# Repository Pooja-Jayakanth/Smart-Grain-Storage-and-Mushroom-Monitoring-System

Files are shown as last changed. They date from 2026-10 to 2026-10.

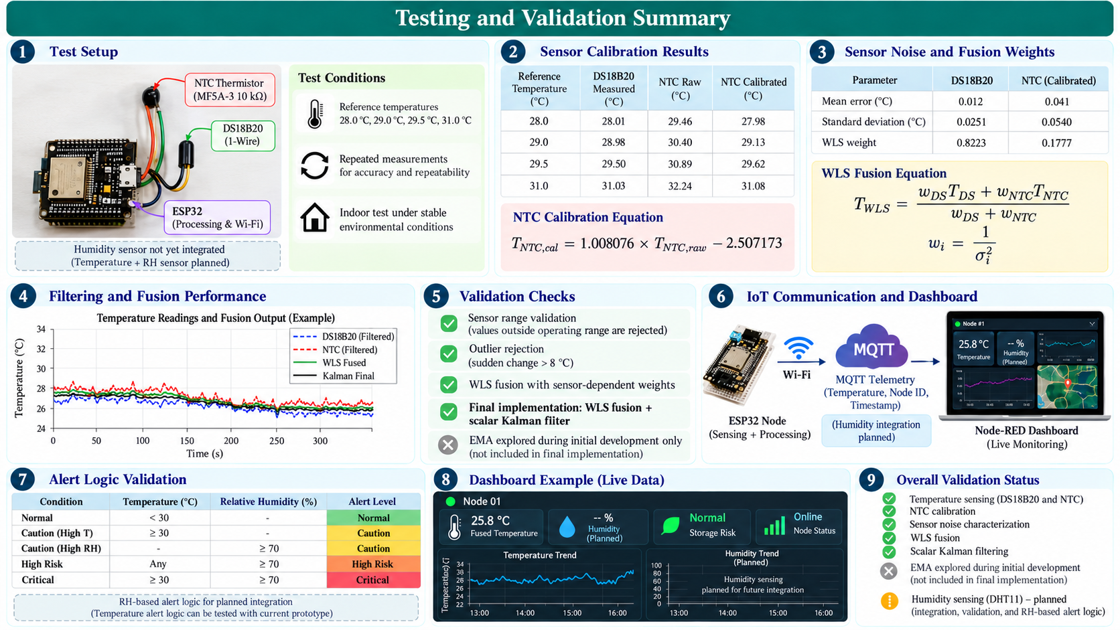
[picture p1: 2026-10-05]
docs/Testing and Validation Summary-Semifinal Prototype.png

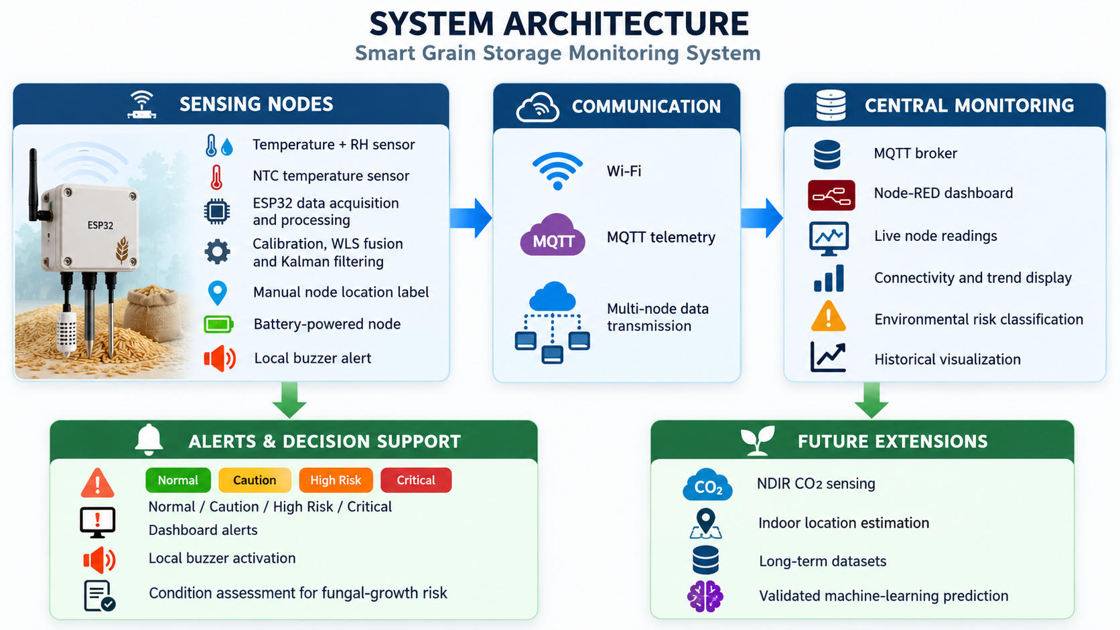
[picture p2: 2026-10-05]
docs/System Architecture.png

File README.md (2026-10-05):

# Smart Grain and Mushroom Monitoring System

## IoTrix 2.0 – Track C
### IoT Product & System Architecture

## Project Overview

The **Smart Grain and Mushroom Monitoring System** is a low-cost distributed IoT platform designed to monitor environmental conditions in **grain-storage facilities and mushroom-growing environments**.

Both applications are highly sensitive to environmental conditions. Temperature and relative humidity can significantly affect grain quality, fungal activity, mushroom growth conditions, and overall storage or cultivation performance.

The system uses multiple smart sensing nodes placed at selected locations within the monitored environment. Each node measures important environmental parameters, performs local processing, and transmits live telemetry to a centralized dashboard.

The project is being developed in three stages:

1. **Semi-final proof-of-concept prototype**
2. **Final competition product-level sensing node**
3. **Future data-driven, CO₂-monitoring, and machine-learning implementation**

---

# Problem Statement

Environmental conditions can vary significantly at different locations within a grain-storage warehouse or mushroom-growing facility.

For grain storage, unfavorable combinations of temperature and humidity can create conditions associated with spoilage, fungal activity, and deterioration.

For mushroom cultivation, temperature and relative humidity must remain within suitable ranges to maintain appropriate growing conditions.

Periodic manual measurements or a single sensing point may not provide sufficient information about spatial variations across the monitored environment.

A distributed monitoring system is therefore needed to:

- Continuously monitor environmental conditions at multiple locations
- Identify abnormal or unfavorable conditions early
- Provide centralized real-time visualization
- Generate local and remote alerts
- Store data for future analysis and predictive modelling

---

# Proposed Solution

The proposed system consists of multiple **ESP32-based smart environmental sensing nodes** deployed at selected locations.

Each node acquires environmental measurements, performs local processing, and transmits the processed data through **Wi-Fi using MQTT** to a centralized **Node-RED dashboard**.

The final system is designed to monitor:

- Temperature
- Relative humidity
- Node connectivity and operating status
- Overall environmental-condition level

The measured parameters will be combined using threshold-based decision logic derived from relevant research papers, technical sources, grain-storage guidance, and mushroom-growing requirements.

The dashboard will provide an interpreted condition such as:

- **NORMAL**
- **WARNING**
- **CRITICAL**

If unfavorable conditions are detected:

- A warning will be displayed on the dashboard
- A local buzzer at the relevant sensing node will be activated

This provides both **remote monitoring** and **local warning capability**.

---

# Target Applications

## Grain Storage Monitoring

The system can be deployed at multiple locations inside grain-storage facilities to monitor conditions associated with grain deterioration and fungal-growth risk.

The main parameters are:

- Fused temperature
- Relative humidity

The system is intended to indicate whether environmental conditions are becoming unfavorable rather than directly claiming the presence of fungal growth.

## Mushroom Environment Monitoring

The same distributed architecture can also be used in mushroom-growing environments.

The sensing nodes can continuously monitor:

- Temperature
- Relative humidity

The dashboard can indicate whether the environmental conditions remain within the selected operating ranges for the target mushroom-growing stage.

The threshold values for grain storage and mushroom monitoring will be application-specific and supported by relevant research and technical references.

---

# Development Stages

## 1. Semi-Final Prototype

The current prototype consists of **two operational wireless sensing nodes** connected to a centralized Node-RED monitoring dashboard.

### Components Used in the Semi-Final Prototype

Each prototype node currently contains:

- ESP32 microcontroller
- DS18B20 temperature sensor
- NTC thermistor
- NEO-6M GPS module
- OLED display
- Power-management circuitry
- Push button

For temperature measurement, a sensor-fusion architecture is implemented.

Temperature measurements from:

- DB18S20
- NTC thermistor

are processed using the:

- Calibration
- Sensor validation
- Outlier rejection
- Weighted Least Squares sensor fusion
- Kalman filtering

---

# Temperature Processing Architecture

```text
DB18S20 Temperature  NTC Temperature
        │               |
        │               |
        |               |
        │               │
        ▼               ▼
    Calibration     Calibration
        │               |
        │               |
        │               │
        └───────┬───────┘
                ▼
        Validity Checking
                ▼
         Outlier Rejection
                ▼
      Weighted Least Squares
          Sensor Fusion
                ▼
         Kalman Filtering
                ▼
       Final Temperature
```

Weighted Least Squares is used because the two temperature sensors have different measurement uncertainties.

Instead of assigning equal importance to both measurements, the fusion algorithm gives greater contribution to the more reliable sensor according to experimentally determined characteristics. Weights are given as inverse variances.

The fused output is then passed through a Kalman filter to reduce short-term fluctuations.

---

# Relative Humidity Measurement

The DHT11 also provides relative-humidity measurements.

Relative humidity is important in both target applications.

### For Grain Storage

Relative humidity contributes to the overall assessment of storage conditions associated with moisture-related deterioration and fungal-growth risk.

### For Mushroom Monitoring

Relative humidity is a key environmental parameter for maintaining suitable mushroom-growing conditions.

The measured RH value will therefore be evaluated together with the fused temperature in the final condition-assessment logic.

---

# Purpose of the GPS Module in the Prototype

The semi-final prototype includes a **NEO-6M GPS module** mainly for:

- Prototype development
- Location verification
- Node-position identification
- Testing
- Demonstration purposes

The GPS is not intended to operate continuously in the final product.

In many real deployments, sensing nodes will remain at known fixed positions. Keeping a GPS module active continuously would therefore add unnecessary hardware operation and power consumption.

---

# GPS Strategy in the Final Product

The custom PCB includes the required connections for temporarily connecting the GPS module.

During deployment, the GPS module can be connected when outdoor position acquisition is required.

The acquired location can then be saved by the system.

After the location has been stored, the GPS module can be removed.

```text
Installation
     ↓
Connect GPS Module
     ↓
Acquire Node Location
     ↓
Save Location Data
     ↓
Remove GPS Module
     ↓
Normal Monitoring Operation
```

This provides location capability when required without requiring a permanent GPS module in every deployed node.

---

# Purpose of the OLED in the Prototype

The OLED display is included in the semi-final prototype mainly for:

- Development
- Debugging
- Sensor verification
- Checking node status
- Demonstrating live operation

The OLED allows the development team to directly observe sensor readings and node status during testing.

---

# OLED Removal in the Final Product

The OLED is not required in the intended final monitoring node.

In practical deployment, the centralized dashboard will be the main user interface.

Removing the OLED from the final node helps to:

- Reduce unnecessary hardware
- Reduce power consumption
- Reduce product cost
- Simplify the sensing node
- Improve suitability for distributed deployment

---

# Final Competition Node Architecture

The final competition version of the sensing node is planned to include:

- ESP32 microcontroller
- DHT11 temperature and relative-humidity sensor
- NTC thermistor
- Buzzer
- Custom PCB
- Power-management circuitry
- Temporary GPS connection capability
- Local configuration / storage capability
- Custom mechanical enclosure

The GPS and OLED used in the development prototype will therefore not remain as continuously operating components in the final deployed node.

---

# Environmental Condition Assessment

The final system evaluates environmental conditions using:

- Fused temperature
- Relative humidity

The condition-assessment thresholds will be selected from relevant research papers and suitable technical sources.

Different threshold sets can be used depending on the selected application:

### Grain Storage Mode

The system will assess whether the environmental conditions are:

- Suitable
- Approaching an unfavorable range
- Associated with increased deterioration / fungal-growth risk

### Mushroom Monitoring Mode

The system will assess whether the environmental conditions are:

- Within the desired cultivation range
- Approaching an unsuitable range
- Outside the selected environmental limits

The system does not treat one sensor reading as direct proof of spoilage, contamination, fungal growth, or crop failure. Instead, it provides an **environmental-risk or suitability indication**.

---

# Condition Levels

```text
NORMAL
   │
   ├── Temperature and RH within selected operating limits
   │
WARNING
   │
   ├── One or more parameters approaching an unfavorable range
   │
CRITICAL
   │
   └── Temperature and/or RH outside selected acceptable limits
```

The exact limits will be documented together with the supporting research references.

---

# Live Telemetry

The system operates as a live IoT telemetry network.

Each sensing node continuously performs:

```text
Environmental Sensing
        ↓
Edge Processing
        ↓
Parameter Combination
        ↓
Condition Evaluation
        ↓
Wi-Fi
        ↓
MQTT
        ↓
Centralized Dashboard
```

Each node has a unique Node ID so that measurements from different locations can be identified independently.

---

# Communication Architecture

The sensing nodes communicate using:

- Wi-Fi
- MQTT
- Structured telemetry messages

```text
Sensing Node 01 ─┐
                 │
Sensing Node 02 ─┼── Wi-Fi
                 │
Sensing Node N ──┘
        ↓
   MQTT Broker
        ↓
     Node-RED
        ↓
Central Dashboard
```

MQTT provides a lightweight publish/subscribe communication method suitable for transmitting measurements from multiple IoT sensing nodes.

---

# Dashboard

The centralized monitoring dashboard is implemented using **Node-RED**.

The final dashboard is intended to display:

- Node ID
- Fused temperature
- Relative humidity
- Node connectivity
- Selected monitoring mode
- Environmental-condition classification
- Warning / critical status
- Historical trends
- Live telemetry
- Node location information
- Alarm indication

The dashboard therefore presents both the measured environmental parameters and the interpreted condition.

---

# Alert System

The final system contains both remote and local alert mechanisms.

## Dashboard Alert

When unfavorable environmental conditions are detected:

- The node status changes
- A warning or critical indication appears
- The affected sensing node is identified

## Local Buzzer Alert

A buzzer installed in the sensing node provides a local warning.

```text
Unfavorable Condition Detected
             ↓
      Decision Algorithm
          ┌──┴──┐
          ↓     ↓
     Dashboard  Buzzer
       Alert    Alert
```

This allows the system to provide an alert both remotely and directly at the monitored location.

---

# Prototype vs Final Product

| Feature | Semi-Final Prototype | Final Competition Model |
|---|---|---|
| ESP32 | ✅ | ✅ |
| DHT11 | ❌ | ✅ |
| DS18B20 | ✅ | ❌ Replaced by DHT11 |
| NTC Thermistor | ✅ | ✅ |
| Temperature Sensor Fusion | ✅ | ✅ |
| Relative Humidity | ✅ | ✅ |
| IRLZ44N | ✅ | ✅ |
| Wi-Fi | ✅ | ✅ |
| MQTT | ✅ | ✅ |
| Node-RED Dashboard | ✅ | ✅ |
| GPS | ✅ Development / verification | Temporary connection only |
| OLED | ✅ Development / verification | ❌ Removed |
| Push button | ✅ | ❌ Removed |
| Buzzer | Under development | ✅ |
| Custom PCB | Designed | ✅ |
| Custom Enclosure | Designed | ✅ |
| Live Telemetry | ✅ | ✅ |
| Grain Condition Assessment | Under development | ✅ |
| Mushroom Condition Assessment | Under development | ✅ |
| CO₂ Monitoring | ❌ | Future implementation |
| Machine Learning | ❌ | Future development |

---

# Current Proof of Concept

At the semi-final stage, the project has achieved:

- Two operational sensing nodes
- DB18S20 temperature measurement
- NTC temperature measurement
- Temperature sensor calibration
- WLS temperature sensor fusion
- Kalman filtering
- Sensor validity checking
- ESP32 edge processing
- Wi-Fi connectivity
- MQTT telemetry
- Node identification
- Centralized Node-RED dashboard
- GPS-based prototype location verification
- OLED-based local prototype visualization
- Custom PCB design
- Mechanical enclosure design

This demonstrates the complete core IoT chain:

```text
Physical Measurement
        ↓
Edge Processing
        ↓
Wireless Communication
        ↓
IoT Messaging
        ↓
Centralized Monitoring
```

---

# Technology Stack

## Hardware

- ESP32
- DHT11 temperature and relative-humidity sensor
- DS18B20 for prototype development
- NTC thermistor
- Buzzer
- NEO-6M GPS for development / temporary location initialization
- OLED for prototype development
- Pushbutton for prototype development
- Custom PCB
- Custom enclosure
- Power-management circuitry
- IRLZ44N MOSFET

## Embedded Processing

- Sensor acquisition
- Calibration
- Validity checking
- Outlier rejection
- Weighted Least Squares sensor fusion
- Kalman filtering
- Temperature and RH condition evaluation
- Alarm control

## Communication

- Wi-Fi
- MQTT
- Structured telemetry payloads

## Monitoring

- Node-RED
- Real-time dashboard
- Multi-node visualization
- Historical trends
- Alerts
- Telemetry logging

---

# Engineering Design Philosophy

## Low Cost

The sensing nodes use low-cost and widely available embedded components so that multiple nodes can be deployed practically.

## Distributed Monitoring

Multiple sensing nodes can be placed at different locations instead of relying on a single measurement point.

## Edge Processing

Important sensor processing is performed directly on the ESP32 before data transmission.

## Modular Architecture

The same node and communication architecture can support different environmental-monitoring applications.

## Reduced Final Hardware

Development-only components such as the OLED and continuously operating GPS are removed from the final product when no longer required.

## Dual-Parameter Monitoring

The current condition assessment uses temperature and relative humidity, which are directly relevant to the environmental suitability of grain storage and mushroom cultivation.

## Dual-Application Architecture

The same sensing platform can support:

- Grain-storage environmental monitoring
- Mushroom-growing environmental monitoring

The monitoring logic and threshold values can be configured according to the selected application.

---

# Current Limitations

The current system is still at the prototype and semi-final development stage.

Current limitations include:

- Buzzer integration is still being completed
- DHT11 calibration and integration is still being completed.
- Grain-condition assessment logic requires final validation
- Mushroom-condition assessment logic requires final validation
- Threshold values must be fully documented using relevant research sources
- The custom PCB requires physical fabrication and validation
- Long-duration testing in representative environments is still required
- Power consumption and battery life require further characterization
- Wi-Fi availability may affect live communication
- Larger-scale multi-node deployment requires further validation

---

# Planned Improvements Before the Final Competition

The following improvements are planned before the final competition:

1. Complete buzzer integration.
2. Finalize the combined temperature and RH assessment logic.
4. Define separate threshold sets for grain storage and mushroom monitoring.
5. Document threshold values using relevant research papers and technical sources.
6. Manufacture and test the custom PCB.
7. Integrate the PCB into the designed enclosure.
8. Remove the OLED from the final node.
9. Implement temporary GPS-based location initialization.
10. Improve the dashboard for multi-parameter monitoring.
11. Add application selection for grain-storage or mushroom-monitoring mode.
12. Implement dashboard and local buzzer alerts.
13. Perform longer-duration sensor and communication testing.
14. Test the system under representative grain-storage and mushroom-growing conditions.
15. Measure power consumption and estimate operating duration.
16. Improve Wi-Fi reconnection and network-loss handling.

---

# Future Implementation – CO₂ Level Monitoring

A future version of the system may include a **dedicated NDIR CO₂ sensor** to provide direct CO₂ concentration measurements in ppm.

CO₂ monitoring could add useful information for both applications.

## Grain Storage

Changes in CO₂ concentration can provide an additional indicator of biological respiration and changing storage conditions. In a future implementation, CO₂ measurements could be evaluated together with fused temperature, relative humidity, and historical trends to strengthen environmental-risk assessment.

## Mushroom Monitoring

CO₂ concentration is an important environmental parameter in mushroom-growing environments. A future node could therefore use direct NDIR CO₂ monitoring together with temperature and relative humidity to provide more complete cultivation-condition monitoring.

The future sensing concept would become:

```text
Temperature
    +
Relative Humidity
    +
NDIR CO₂ Measurement
    ↓
Improved Environmental
Condition Assessment
```

A dedicated NDIR sensor would be used rather than estimating CO₂ indirectly.

---

# Future Development – Data Logging and Machine Learning

The current system uses research-based thresholds and interpretable engineering decision logic.

As a future development, long-term environmental data collected from deployed sensing nodes will be stored and used to develop application-specific datasets.

The datasets may include:

- Temperature
- Relative humidity
- CO₂ concentration when future CO₂ sensing is implemented
- Time information
- Node / location information
- Selected application
- Environmental-condition classification
- Verified grain-quality observations where reliable labels are available
- Verified mushroom-growth or environmental observations where reliable labels are available

These datasets can later be used to investigate machine-learning methods for more advanced prediction.

## Future Grain Monitoring

A validated model could be investigated for earlier identification of environmental patterns associated with grain deterioration risk.

## Future Mushroom Monitoring

A separate validated model could be investigated for identifying environmental patterns associated with suitable or unsuitable mushroom-growing conditions.

The long-term development path is:

```text
Live IoT Monitoring
        ↓
Historical Data Collection
        ↓
Dataset Development
        ↓
CO₂ Monitoring Extension
        ↓
Data Analysis
        ↓
Machine-Learning Model Training
        ↓
Model Validation
        ↓
Deployment of Validated Model
        ↓
Improved Predictive Monitoring
```

Machine learning is considered a future enhancement rather than a requirement for the current proof of concept.

The current threshold-based system provides an interpretable engineering baseline before sufficient representative and correctly labelled field data are available for model training.

---

# Expected Final System Architecture

```text
       SMART GRAIN & MUSHROOM
          MONITORING SYSTEM

 ┌─────────────────────────────────────┐
 │               NODE 01               │
 │                                     │
 │ DHT11 → Temperature + RH            │
 │ NTC   → Temperature                 │
 │                                     │
 │                                     │
 │ ESP32                               │
 │ ├── Calibration                     │
 │ ├── Sensor Validation               │
 │ ├── Temperature Sensor Fusion       │
 │ ├── Kalman Filtering                │
 │ ├── Condition Assessment            │
 │ └── Alarm Logic                     │
 │                                     │
 │ Buzzer                              │
 └──────────────────┬──────────────────┘
                    │
                    │ Wi-Fi / MQTT
                    │
        ┌───────────┴───────────┐
        │                       │
      NODE 02                 NODE N
        │                       │
        └───────────┬───────────┘
                    ▼
               MQTT Broker
                    ▼
                 Node-RED
                    ▼
            CENTRAL DASHBOARD
                    │
       ┌────────────┼────────────┐
       ▼                         ▼
 Temperature                     RH
       │                         │
       └────────────┼────────────┘
                    ▼
       Application-Specific
        Condition Assessment
                    ▼
         NORMAL / WARNING /
              CRITICAL

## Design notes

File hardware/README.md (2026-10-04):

# Hardware

This folder contains the hardware design files for the Smart Grain Storage and Mushroom Monitoring System.

The current hardware development includes the sensing-node schematic, PCB design, bill of materials, and mechanical enclosure design.

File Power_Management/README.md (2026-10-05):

Power management calculations of the System

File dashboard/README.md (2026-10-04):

# Dashboard 

## Overview

This folder contains the dashboard implementation for the **Smart Grain Storage and Mushroom Monitoring System for Sri Lankan grain storage facilities**.

The dashboard receives environmental data from multiple ESP32-based wireless sensor nodes through **Wi-Fi and MQTT** and provides centralized real-time monitoring using **Node-RED**.

The main purpose of the dashboard is to help identify storage conditions that may increase the risk of fungal growth and grain deterioration by monitoring parameters such as:

- Temperature
- Relative humidity
- Temperature variation over time
- Battery status
- Wi-Fi signal strength
- Node connectivity
- Risk level
- Alarm condition

> The system does not directly identify or confirm the presence of fungi.  
> It identifies environmental conditions and trends that may indicate an increased risk of fungal growth and grain deterioration.

---

## System Architecture

```text
        SMART GRAIN STORAGE MONITORING SYSTEM

 ┌──────────────────────┐
 │     Sensor Node 01   │
 │ Temperature          │
 │ Humidity             │
 │ NTC Temperature      │
 │ Battery Monitoring   │
 └──────────┬───────────┘
            │
            │
 ┌──────────▼───────────┐
 │     Sensor Node 02   │
 │ Temperature          │
 │ Humidity             │
 │ NTC Temperature      │
 │ Battery Monitoring   │
 └──────────┬───────────┘
            │
            │
 ┌──────────▼───────────┐
 │     Sensor Node N    │
 └──────────┬───────────┘
            │
            │ Wi-Fi
            ▼
 ┌──────────────────────┐
 │ Wi-Fi Router / AP    │
 └──────────┬───────────┘
            │
            ▼
 ┌──────────────────────┐
 │     MQTT Broker      │
 └──────────┬───────────┘
            │
            ▼
 ┌──────────────────────┐
 │       Node-RED       │
 │      Dashboard       │
 └──────────┬───────────┘
            │
   ┌────────┼───────────────┐
   │        │               │
   ▼        ▼               ▼
Live Data  Trends        Alerts
   │
   ▼
Storage Zone Monitoring

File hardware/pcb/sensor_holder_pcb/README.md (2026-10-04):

# Sensor Holder PCB

This folder consists of all the files related to the sensor holder PCB.

This sensor holder PCB consists of our both sensors NTC Thermistor and DHT11 Temperature and relative humidity sensor.

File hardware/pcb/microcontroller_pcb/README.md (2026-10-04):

# Microcontroller PCB

This folder consists of all the files related to the Microcontroller section.

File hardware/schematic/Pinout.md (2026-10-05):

# Temperature Node – Pinout / Connection List

---

## 1. ESP-12F / ESP8266 Main Pinout
__________________________________________________________________________________________________________________________
| ESP-12F Pin | ESP-12F Signal | PCB Connection | Connected Component / Net | External / Manual Connection |
|---|---|---|---|---|
| 1 | RST | Reset circuit | R9.1, SW4.1/SW4.2, 10 kΩ pull-up | |
| 2 | ADC | External header | R2.1, **H2.5** | NTC 10 kohm |
| 3 | EN | Pull-up | R5.1, 10 kΩ pull-up network | |
| 4 | IO16 | Pull-up | R6.1, 10 kΩ pull-up | |
| 5 | IO14 | NC | Not connected in schematic | |
| 6 | IO12 | NC | Not connected in schematic | |
| 7 | IO13 | NC | Not connected in schematic | |
| 8 | VCC | 3.3 V rail | U7 VOUT, C2/C3, CN4.4, H2.2 | |
| 9 | CS0 | NC | Not connected in schematic | |
| 10 | MISO | NC | Not connected in schematic | |
| 11 | IO9 | Buzzer | U8.1 | |
| 12 | IO10 | NC | Not connected in schematic | |
| 13 | MOSI | NC | Not connected in schematic | |
| 14 | SCLK | MOSFET gate drive | R3.2 → R3 100 Ω → Q1 gate | |
| 15 | GND | Ground | GND / H2.1 / H2.4 / U5.2 / SW3.4 | |
| 16 | IO15 | Boot pull-down | R8.2, R8.1 → GND | |
| 17 | IO2 | Pull-up | R7.1, 10 kΩ pull-up | |
| 18 | IO0 | Programming / boot| R7.1, U5.1; jumper to GND through U5 | |
| 19 | IO4 | External header | **H2.3** | DS18B20 Temparature sensor |
| 20 | IO5 | Push button | SW3.1; SW3.4 → GND | |
| 21 | RXD | External header | **CN4.3** | Header for programming & GPS |
| 22 | TXD | External header | **CN4.2** | Header for programming & GPS |

---

## 2. External Connector CN4 – 4 Pin Header

**Part:** HC-EH2.54-4A-TW  
**PCB footprint:** 1×4, 2.5 mm pitch
______________________________________________________________________________
| CN4 Pin | PCB Net / Connection | Manual External Function |
|---|---|---|
| 1 | Q1 Drain / MOSFET switched output | GND of GPS (optional) |
| 2 | ESP-12F TXD (Pin 22) | Header for programming & GPS |
| 3 | ESP-12F RXD (Pin 21) | Header for programming & GPS |
| 4 | 3.3 V / ESP-12F VCC | VCC of GPS (optional) |

---

## 3. External Header H2 – 5 Pin Header

**Part:** 1×5, 2.54 mm pitch
_____________________________________________________________
| H2 Pin | PCB Connection | Manual External Function |
|---|---|---|
| 1 | GND | GND of DS18B20 |
| 2 | 3.3 V | VCC of DS18B20 |
| 3 | ESP-12F IO4 (Pin 19)  | Input pin for DS18B20 |
| 4 | GND | GND of NTC |
| 5 | ESP-12F ADC (Pin 2) | Input pin for NTC data |

---

## 4. Power Connector CN5 – 2 Pin

**Part:** JST-PH-2-SMT-RA
___________________________________
| CN5 Pin | PCB Connection |
|---|---|
| 1 | U7 VIN / input supply |
| 2 | GND |

### Power path

`CN5.1 → U7 VIN → AMS1117-3.3 → 3.3 V`

`CN5.2 → GND`

---

## 5. Programming Jumper U5

**Part:** 2-pin jumper
__________________________________________________________________________
| U5 Pin | Connection | Function |
|---|---|---|
| 1 | ESP-12F IO0 / Pin 18 | Short circuited while upload programme |
| 2 | GND | Short circuited while upload programme |

### Programming operation

For ESP8266 UART programming:

**U5 ON / shorted:** IO0 → GND

**U5 OFF / open:** IO0 pulled HIGH for normal boot

---

## 6. Push Button for getting GPS locatiion SW3
___________________________________________________
| SW3 Pin | Connection |
|---|---|
| 1 | ESP-12F IO5 / Pin 20 |
| 2 | Not explicitly connected in schematic |
| 3 | Not explicitly connected in schematic |
| 4 | GND |

---

## 7. Reset Button SW4
___________________________________________________
| SW4 Pin | Connection |
|---|---|
| 1 | ESP-12F RST / Pin 1 |
| 2 | ESP-12F RST / Pin 1 |
| 3 | GND |
| 4 | Not explicitly connected in schematic |

---

## 8. MOSFET Q1

**Part:** IRLZ44PBF
_______________________________________________________________
| Q1 Pin | MOSFET Pin Name | PCB Connection |
|---|---|---|
| 1 | Gate (G) | R3.1 → R3 100 Ω → ESP-12F Pin 14 |
| 2 | Drain (D) | CN4.1 |
| 3 | Source (S) | GND through R4/R8 ground network |

---

## 9. Buzzer U8

**Part:** HX-2212
_________________________________
| U8 Pin | Connection |
|---|---|
| 1 | ESP-12F IO9 / Pin 11 |
| 2 | GND |

---

## 10. Voltage Regulator U7

**Part:** AMS1117-3.3
__________________________________
| U7 Pin | Function | Connection |
|---|---|---|
| 1 | GND | GND |
| 2 | VOUT | 3.3 V rail |
| 3 | VIN | CN5.1 |
| 4 | VOUT | 3.3 V rail |

---

## 11. Important Pull-Up / Pull-Down Resistors
______________________________________________________
| Resistor | Value | Connection |
|---|---|---|
| R2 | 10 kΩ | 3.3 V → ESP ADC |
| R3 | 100 Ω | ESP Pin 14 → MOSFET gate |
| R4 | 10 kΩ | MOSFET gate → GND |
| R5 | 10 kΩ | ESP EN pull-up |
| R6 | 10 kΩ | ESP IO16 pull-up |
| R7 | 10 kΩ | ESP IO2 / IO0 pull-up network |
| R8 | 10 kΩ | ESP IO15 pull-down |
| R9 | 10 kΩ | ESP RST pull-up |

---

## 12. Capacitors
______________________________________________
| Capacitor | Value | Connection |
|---|---|---|
| C1 | 10 µF | Input supply filtering |
| C2 | 10 µF | 3.3 V output filtering |
| C3 | 100 nF| 3.3 V decoupling |

---

# 14. ESP8266 GPIO Usage Summary
___________________________________________________________
| GPIO | ESP-12F Pin | Current Use |
|---|---|---|
| GPIO0 | 18 | Programming / boot jumper |
| GPIO1 / TXD | 22 | UART TX → CN4.2 |
| GPIO2 | 17 | Pull-up / boot |
| GPIO3 / RXD | 21 | UART RX ← CN4.3 |
| GPIO4 | 19 | H2.3 external |
| GPIO5 | 20 | SW3 button |
| GPIO6 | 9 | Flash interface / CS0 |
| GPIO7 | 13 | Flash interface / MOSI |
| GPIO8 | 12 | Flash interface / IO10 |
| GPIO9 | 11 | Buzzer |
| GPIO10 | 12 | Flash interface / IO10 |
| GPIO12 | 6 | NC |
| GPIO13 | 7 | NC |
| GPIO14 | 5 | NC |
| GPIO15 | 16 | Boot pull-down |
| GPIO16 | 4 | Pull-up |
| ADC0 | 2 | H2.5 external ADC |
| RST | 1 | Reset switch |
| EN | 3 | 10 kΩ pull-up |
| VCC | 8 | 3.3 V |
| GND | 15 | Ground |

---

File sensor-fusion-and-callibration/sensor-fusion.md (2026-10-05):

# Sensor Fusion Pipeline — Semi-Finals Prototype

## 1. Sensor-Fusion Objective

The purpose of the sensor-fusion subsystem is to obtain a temperature estimate that is more reliable than depending on only one sensor.

The two temperature sensors use different measurement principles:

- **DS18B20** — digital temperature sensor using the 1-Wire interface.
- **NTC thermistor** — analog resistive temperature sensor read using the ESP32 ADC through a voltage-divider circuit.

Because the two sensors have different levels of noise, calibration error, and measurement uncertainty, they are **not treated as equally reliable**.

The processing method was developed in stages.

### Initial Development

```text
Raw Sensor Measurement
        ↓
EMA Filtering
        ↓
Filtered Sensor Measurement
```

### Final Implemented Processing

```text
Sensor Acquisition
        ↓
Calibration
        ↓
Range Validation
        ↓
Outlier Rejection
        ↓
Sensor Validity Check
        ↓
Weighted Least Squares (WLS) Fusion
        ↓
Fused Temperature + Fused Variance
        ↓
Scalar Kalman Filter
        ↓
Final Temperature Estimate
```

---

## 2. Sensors Used

### 2.1 DS18B20

The DS18B20 provides a direct digital temperature value to the ESP32.

**Main features**

- Digital temperature measurement
- 1-Wire communication
- Does not require the ESP32 ADC
- Lower measured noise than the NTC sensor
- Provides one independent temperature measurement for fusion
- Uses a **4.7 kΩ pull-up resistor** on the data line

The DS18B20 path is:

```text
DS18B20
   ↓
Digital Temperature Reading
   ↓
Calibration
   ↓
Validation
   ↓
Outlier Rejection
   ↓
WLS Fusion
```

### 2.2 MF5A-3 10 kΩ NTC Thermistor

The MF5A-3 is the analog temperature sensor used in the prototype.

The thermistor is connected as a voltage divider:

```text
3.3 V
  │
10 kΩ Fixed Resistor
  │
  ├── ESP32 ADC
  │
10 kΩ NTC
  │
 GND
```

Parameters used:

| Parameter | Value |
|---|---:|
| Nominal resistance, R₀ | 10 kΩ |
| Reference temperature, T₀ | 298.15 K |
| Beta constant, B | 3950 K |
| ESP32 ADC resolution | 12 bit |
| Maximum ADC count | 4095 |

The NTC path is:

```text
NTC Voltage Divider
        ↓
ADC Sampling
        ↓
20-Sample Averaging
        ↓
Resistance Calculation
        ↓
Beta Equation
        ↓
Raw NTC Temperature
        ↓
Linear Calibration
        ↓
Validation
        ↓
Outlier Rejection
        ↓
WLS Fusion
```

---

## 3. NTC ADC Averaging

The NTC ADC reading is averaged over **20 samples** before converting it to resistance.

The 20 ADC samples are:

```math
ADC_1,\ ADC_2,\ ADC_3,\ldots,\ ADC_{20}
```

The average ADC value is:

```math
ADC_{\mathrm{avg}}
=
\frac{1}{20}\sum_{i=1}^{20} ADC_i
```

This averaged value is used in the resistance calculation.

---

## 4. NTC Resistance Calculation

The NTC resistance is calculated from the voltage-divider output as:

```math
R_{\mathrm{NTC}}
=
R_{\mathrm{fixed}}
\frac{ADC_{\mathrm{avg}}}
{ADC_{\max}-ADC_{\mathrm{avg}}}
```

where:

```math
R_{\mathrm{fixed}} = 10{,}000\ \Omega
```
```math
ADC_{\max}=4095
```

for the 12-bit ESP32 ADC.

---

## 5. NTC Resistance-to-Temperature Conversion

The measured NTC resistance is converted to temperature using the Beta equation:

```math
\frac{1}{T_K}
=
\frac{1}{T_0}
+
\frac{1}{B}
\ln\left(
\frac{R_{\mathrm{NTC}}}{R_0}
\right)
```

where:

```math
T_0 = 298.15\ \mathrm{K}
```
```math
R_0 = 10{,}000\ \Omega
```
```math
B = 3950\ \mathrm{K}
```

The raw NTC temperature in degrees Celsius is:

```math
T_{\mathrm{NTC,raw}}
=
T_K - 273.15
```

---

## 6. Sensor Calibration

Both temperature sensors were experimentally compared against a reference thermometer at:

- 28.0 °C
- 29.0 °C
- 29.5 °C
- 31.0 °C

The calibration stage was used to distinguish **systematic measurement error** from **random measurement variation**.

### 6.1 DS18B20 Calibration

The DS18B20 did not show a consistent fixed positive or negative bias across the tested temperatures.

Therefore, no additional linear correction was applied.

```math
T_{\mathrm{DS,cal}}
=
T_{\mathrm{DS,raw}}
```

The calibration coefficients are therefore:

```math
A_{\mathrm{DS}}=1
```
```math
B_{\mathrm{DS}}=0
```

### 6.2 NTC Calibration

The NTC showed a systematic positive offset and therefore required linear calibration.

The general calibration equation is:

```math
T_{\mathrm{cal}}
=
A\,T_{\mathrm{raw}} + B_c
```

The experimentally obtained coefficients for the NTC are:

```math
A_{\mathrm{NTC}}=1.008076
```
```math
B_{\mathrm{NTC}}=-2.507173
```

Therefore:

```math
T_{\mathrm{NTC,cal}}
=
1.008076\,T_{\mathrm{NTC,raw}}
-
2.507173
```

This calibrated NTC temperature is used for fusion.

---

## 7. Initial EMA Filtering Stage

During the initial development stage, an **Exponential Moving Average (EMA)** filter was tested to reduce short-term fluctuations in the individual sensor measurements.

The EMA equation is:

```math
T_{\mathrm{EMA},k}
=
\alpha T_k+(1-\alpha)T_{\mathrm{EMA},k-1}
```

where:

- **T(k)** = current sensor measurement
- **T_EMA(k−1)** = previous filtered value
- **T_EMA(k)** = new filtered value
- **α** = smoothing coefficient

The value used during testing was:

```math
\alpha = 0.20
```

Therefore:

```math
T_{\mathrm{EMA},k}
=
0.20T_k
+
0.80T_{\mathrm{EMA},k-1}
```

The initial development flow was:

```text
DS18B20 Raw
    ↓
EMA
    ↓
Filtered DS18B20

NTC Raw
    ↓
EMA
    ↓
Filtered NTC
```

EMA was useful because it:

- required very little memory,
- required low computation,
- reduced sample-to-sample fluctuations,
- and was simple to implement on the ESP32.

However, EMA only performs **temporal smoothing**. It does not determine how much each sensor should be trusted relative to the other.

For that reason, EMA was not used as the final fusion method.

---

## 8. Measurement Validation

Before sensor fusion, each calibrated temperature is checked for validity.

The prototype applies two main checks.

### 8.1 Range Validation

The selected valid operating range is:

```math
-20^\circ\mathrm{C}
<
T
<
100^\circ\mathrm{C}
```

Measurements at or outside the limits are rejected.

### 8.2 Sudden-Change Rejection

A new measurement is rejected if the change from the previous accepted measurement is greater than:

```math
8^\circ\mathrm{C}
```

That is:

```math
\left|T_k-T_{k-1}\right|
>
8^\circ\mathrm{C}
```

is treated as an invalid sudden change.

This check helps reject:

- disconnected-sensor readings,
- transient ADC disturbances,
- conversion errors,
- unrealistic spikes.

---

## 9. Sensor Noise Characterization

The measured standard deviations from the 100-sample characterization test were:

```math
\sigma_{\mathrm{DS}}
=
0.0251^\circ\mathrm{C}
```
```math
\sigma_{\mathrm{NTC}}
=
0.0540^\circ\mathrm{C}
```

The DS18B20 therefore showed lower random variation than the NTC.

These measured values are used directly in the WLS fusion algorithm.

---

## 10. Weighted Least Squares Sensor Fusion

The final fusion method is **inverse-variance Weighted Least Squares (WLS)**.

The main idea is:

> A sensor with lower experimentally measured variance is given a larger weight.

The variance of each sensor is:

```math
\sigma_{\mathrm{DS}}^2
=
(0.0251)^2
=
0.000630
```

```math
\sigma_{\mathrm{NTC}}^2
=
(0.0540)^2
=
0.002916
```

### 10.1 Information Values

For each sensor, the information value is the inverse of its variance:

```math
I_{\mathrm{DS}}
=
\frac{1}{\sigma_{\mathrm{DS}}^2}
```

```math
I_{\mathrm{NTC}}
=
\frac{1}{\sigma_{\mathrm{NTC}}^2}
```

A lower sensor variance therefore produces a larger information value.

### 10.2 WLS Weights

The information values are normalized to obtain the sensor weights:

```math
w_{\mathrm{DS}}
=
\frac{I_{\mathrm{DS}}}
{I_{\mathrm{DS}}+I_{\mathrm{NTC}}}
```

```math
w_{\mathrm{NTC}}
=
\frac{I_{\mathrm{NTC}}}
{I_{\mathrm{DS}}+I_{\mathrm{NTC}}}
```

The experimentally derived weights are approximately:

```math
w_{\mathrm{DS}}\approx0.822
```
```math
w_{\mathrm{NTC}}\approx0.178
```

and:

```math
w_{\mathrm{DS}}+w_{\mathrm{NTC}}=1
```

This means that the DS18B20 contributes more strongly because it showed lower measured noise.

### 10.3 Fused Temperature

The WLS fused temperature is:

```math
T_{\mathrm{WLS}}
=
w_{\mathrm{DS}}T_{\mathrm{DS}}
+
w_{\mathrm{NTC}}T_{\mathrm{NTC}}
```

Using the experimentally obtained weights:

```math
T_{\mathrm{WLS}}
=
0.822\,T_{\mathrm{DS}}
+
0.178\,T_{\mathrm{NTC}}
```

Therefore:

- DS18B20 contribution ≈ 82.2%
- NTC contribution ≈ 17.8%

The NTC is still retained as an independent second temperature measurement, providing redundancy.

---

## 11. Fused Measurement Variance

WLS also produces an uncertainty value for the fused measurement.

The fused variance is:

```math
R_{\mathrm{WLS}}
=
\frac{1}
{
\frac{1}{\sigma_{\mathrm{DS}}^2}
+
\frac{1}{\sigma_{\mathrm{NTC}}^2}
}
```

This value represents the uncertainty of the WLS fused temperature.

The WLS stage therefore produces two important outputs:

- `T_WLS` — fused temperature
- `R_WLS` — fused measurement variance

The fused variance is passed directly to the Kalman filter as the measurement-noise term.

---

## 12. Fault-Tolerant Fusion

The fusion stage checks the validity of both temperature sensors.

### Both Sensors Valid

Normal WLS fusion is used:

```math
T_{\mathrm{WLS}}
=
0.822\,T_{\mathrm{DS}}
+
0.178\,T_{\mathrm{NTC}}
```

### Only DS18B20 Valid

- **w_DS = 1**
- **w_NTC = 0**

Therefore:

```math
T_{\mathrm{WLS}}=T_{\mathrm{DS}}
```

### Only NTC Valid

- **w_DS = 0**
- **w_NTC = 1**

Therefore:

```math
T_{\mathrm{WLS}}=T_{\mathrm{NTC}}
```

### Both Sensors Invalid

The fusion result is declared invalid.

```text
DS18B20 Invalid
       +
NTC Invalid
       ↓
Fusion Invalid
       ↓
No false temperature output
```

This allows the system to continue operating when only one temperature sensor fails.

---

## 13. Kalman Filtering After WLS

WLS combines the two simultaneous temperature measurements at a single sampling instant.

The Kalman filter then uses the sequence of WLS results over time.

```text
WLS
 ↓
Combines the two sensors at one sampling instant

Kalman Filter
 ↓
Tracks and smooths the fused temperature over time
```

The Kalman filter provides temporal smoothing while considering the uncertainty generated by the WLS stage.

---

## 14. Kalman Filter State

The state being estimated is the true temperature:

```math
x_k=T_k
```

---

## 15. Prediction Step

The predicted temperature is assumed to remain close to the previous estimate:

```math
\hat{x}_{k|k-1}
=
\hat{x}_{k-1|k-1}
```

The predicted covariance is:

```math
P_k^{-}
=
P_{k-1}+Q
```

---

## 16. Process Noise

The process-noise standard deviation used in the prototype is:

```math
\sigma_Q=0.10
```

Therefore:

```math
Q=(0.10)^2=0.01
```

This term represents expected real temperature variation between consecutive samples.

---

## 17. Measurement Noise

The measurement-noise term used by the Kalman filter is obtained directly from WLS:

```math
R_k=R_{\mathrm{WLS}}
```

This directly connects the WLS stage to the Kalman filter.

---

## 18. Kalman Gain

The Kalman gain is calculated as:

```math
K_k
=
\frac{P_k^{-}}
{P_k^{-}+R_k}
```

Interpretation:

- Smaller **R(k)** → greater confidence in the new WLS measurement
- Larger **R(k)** → greater reliance on the predicted temperature

---

## 19. Kalman Measurement Update

The WLS fused temperature becomes the Kalman measurement input:

```math
z_k=T_{\mathrm{WLS}}
```

The updated temperature estimate is:

```math
\hat{x}_k
=
\hat{x}_{k|k-1}
+
K_k\left(
z_k-\hat{x}_{k|k-1}
\right)
```

The covariance is then updated as:

```math
P_k
=
(1-K_k)P_k^{-}
```

The resulting value **x̂(k)** is the final temperature estimate.

---

## 20. Complete Sensor-Fusion Flow

```text
                         DS18B20
                            │
                            ▼
                 Digital Temperature
                            │
                            ▼
                       Calibration
                  T_DS,cal = T_DS,raw
                            │
                            ▼
                    Range Validation
                            │
                            ▼
                    Outlier Rejection
                            │
                            ▼
                     Validity Check
                            │
                            │
                            ├───────────────┐
                            │               │
                            │               ▼
                            │          WLS SENSOR
                            │            FUSION
                            │               ▲
                            │               │
                            │               │
                         NTC Thermistor     │
                            │               │
                            ▼               │
                    ESP32 ADC Sampling      │
                            │               │
                            ▼               │
                    20-Sample Average       │
                            │               │
                            ▼               │
                  Resistance Calculation    │
                            │               │
                            ▼               │
                      Beta Equation         │
                            │               │
                            ▼               │
                     T_NTC,raw              │
                            │               │
                            ▼               │
                    Linear Calibration      │
                            │               │
                            ▼               │
                     T_NTC,cal              │
                            │               │
                            ▼               │
                    Range Validation        │
                            │               │
                            ▼               │
                    Outlier Rejection       │
                            │               │
                            ▼               │
                     Validity Check         │
                            │               │
                            └───────────────┘
                                    │
                                    ▼
                     Weighted Least Squares
                                    │
                         ┌──────────┴──────────┐
                         │                     │
                         ▼                     ▼
                    T_WLS                 R_WLS
                         │                     │
                         └──────────┬──────────┘
                                    ▼
                         Scalar Kalman Filter
                                    │
                                    ▼
                       Final Temperature Estimate
```

---

## 21. Development Flow from EMA to Final Fusion

```text
INITIAL DEVELOPMENT
───────────────────

Raw DS18B20 ──→ EMA ──→ Filtered DS18B20

Raw NTC ──────→ EMA ──→ Filtered NTC

Purpose:
Evaluate basic short-term noise reduction.

        ↓

SENSOR CHARACTERIZATION
───────────────────────

Reference Temperature Testing
        ↓
Calibration
        ↓
Noise Measurement
        ↓
Standard Deviation
        ↓
Sensor Variance

        ↓

FINAL IMPLEMENTATION
────────────────────

DS18B20 + NTC
        ↓
Sensor Acquisition
        ↓
NTC 20-Sample ADC Averaging
        ↓
NTC Temperature Conversion
        ↓
Calibration of Both Sensors
        ↓
Range Validation
        ↓
Sudden-Change / Outlier Rejection
        ↓
Sensor Validity Decision
        ↓
Inverse-Variance WLS Fusion
        ↓
T_WLS + R_WLS
        ↓
Scalar Kalman Filter
        ↓
Final Temperature Estimate
```

---

## 22. Why the Final Method Was Selected

The final architecture is:

```text
Calibration
    ↓
Validity Checking
    ↓
WLS Sensor Fusion
    ↓
Kalman Filtering
```

This approach was selected because:

- the two sensors have different measured uncertainties,
- WLS uses measured sensor variance rather than arbitrary weighting,
- the more reliable sensor automatically receives a larger weight,
- the second sensor still provides redundancy,
- one sensor can temporarily replace the other during a fault,
- WLS produces a fused measurement variance,
- the fused variance can be passed directly to the Kalman filter,
- the Kalman filter smooths the fused temperature over time,
- the complete method is computationally suitable for the ESP32,
- and the method is transparent and easy to justify experimentally.

---

## 23. Why EMA Was Replaced

EMA was useful for initial filtering.

Its equation is:

```math
T_{\mathrm{EMA},k}
=
\alpha T_k+(1-\alpha)T_{\mathrm{EMA},k-1}
```

However, EMA uses a fixed coefficient **α**.

It does not use the experimentally measured variance of each sensor.

WLS instead uses:

```math
w_i\propto\frac{1}{\sigma_i^2}
```

so the sensor weights come directly from measured sensor performance.

Therefore:

```text
EMA
 ↓
Initial temporal smoothing investigation

WLS
 ↓
Final multi-sensor fusion

Kalman Filter
 ↓
Final temporal estimation and smoothing
```

---

## 24. Why Simple Averaging Was Not Used

A simple average would be:

```math
T_{\mathrm{avg}}
=
\frac{T_{\mathrm{DS}}+T_{\mathrm{NTC}}}{2}
```

which assumes:

```math
w_{\mathrm{DS}}=0.5
```
```math
w_{\mathrm{NTC}}=0.5
```

This would incorrectly treat both sensors as equally reliable.

The measured standard deviations show that the sensors are not equally reliable.

Therefore, inverse-variance WLS was selected instead.

---

## 25. Why Median Fusion Was Not Used

Median fusion is useful when at least three redundant measurements are available.

This prototype uses only two independent temperature sensors.

Therefore, median-based voting cannot provide meaningful majority-based fault rejection.

---

## 26. Why Complementary Filtering Was Not Used

Complementary filtering is typically useful when two sensors provide complementary information over different frequency ranges.

In this system:

- DS18B20 measures temperature.
- NTC thermistor measures temperature.

Both sensors measure the same physical quantity over the same timescale.

Therefore, a complementary filter does not provide a clear advantage.

---

## 27. Why an Extended Kalman Filter Was Not Required

The NTC measurement starts with a nonlinear resistance-to-temperature relationship.

However, that nonlinearity is handled before sensor fusion:

```text
NTC Resistance
      ↓
Beta Equation
      ↓
Temperature
      ↓
Linear Calibration
```

By the time fusion begins:

```text
DS18B20 → Temperature in °C
NTC     → Temperature in °C
```

Both inputs are already temperature values in the same domain.

Therefore, a nonlinear estimator such as an Extended Kalman Filter is not required.

---

## 28. Key Prototype Parameters

| Parameter | Value |
|---|---:|
| DS18B20 sensor | Digital temperature sensor |
| NTC sensor | MF5A-3 10 kΩ |
| NTC fixed resistor | 10 kΩ |
| NTC Beta constant | 3950 K |
| ESP32 ADC resolution | 12 bit |
| ADC maximum | 4095 |
| NTC ADC averaging | 20 samples |
| Calibration points | 28.0, 29.0, 29.5, 31.0 °C |
| DS18B20 calibration | `T_cal = T_raw` |
| NTC calibration slope | 1.008076 |
| NTC calibration offset | −2.507173 |
| DS18B20 standard deviation | 0.0251 °C |
| NTC standard deviation | 0.0540 °C |
| DS18B20 WLS weight | ≈ 0.822 |
| NTC WLS weight | ≈ 0.178 |
| EMA test coefficient | 0.20 |
| Sudden-change rejection | > 8 °C |
| Validation range | −20 °C < T < 100 °C |
| Kalman process-noise standard deviation | 0.10 |
| Kalman process noise, Q | 0.01 |
| Kalman measurement noise | `R(k) = R_WLS` |

---

## 29. Final Sensor-Fusion Summary

For the **semi-finals prototype**, the complete temperature-estimation path is:

```text
DS18B20 + MF5A-3 NTC
        ↓
Sensor Acquisition
        ↓
NTC 20-Sample ADC Averaging
        ↓
Temperature Conversion
        ↓
Sensor Calibration
        ↓
Range Validation
        ↓
Outlier Rejection
        ↓
Sensor Validity / Fault Handling
        ↓
Inverse-Variance WLS Sensor Fusion
        ↓
Fused Temperature T_WLS
+
Fused Variance R_WLS
        ↓
Scalar Kalman Filter
        ↓
Final Temperature Estimate
```

The **EMA filter is retained as part of the development history**, while the **final implemented sensor-fusion architecture is WLS followed by scalar Kalman filtering**.

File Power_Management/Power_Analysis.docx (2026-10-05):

POWER ANALYSIS AND BATTERY SELECTION

ESP-12F Temperature / Humidity Monitoring Node with 5-Minute MQTT Transmission

Engineering project article — design calculation, battery sizing and low-power operating strategy

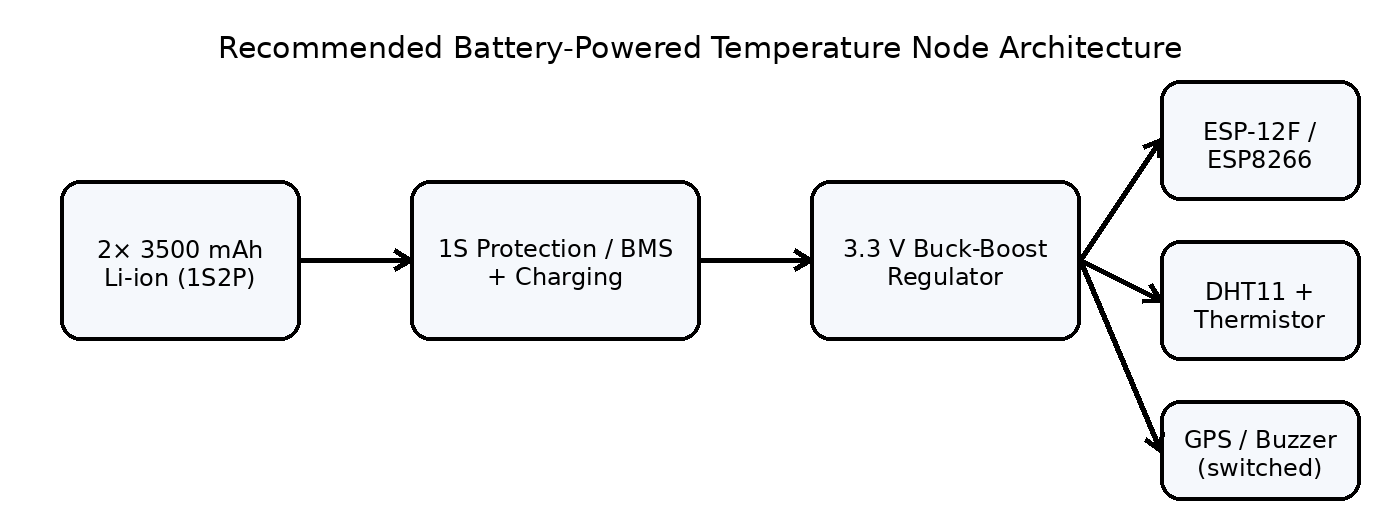
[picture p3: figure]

Figure 1. Recommended power architecture for the battery-powered temperature node.

# 1. System Definition

The proposed node uses an ESP-12F/ESP8266 as the wireless controller. A DHT11 measures ambient temperature and relative humidity, while an external thermistor provides an additional temperature measurement through an analogue divider. The GPS receiver is not a continuous sensing load: it is used only during initialization to obtain the node location, after which the location can be stored and the GPS powered off. The measured data are transmitted to the MQTT server once every 5 minutes.

For a long-life battery design, the ESP8266 should not remain connected to Wi-Fi continuously. The recommended operating sequence is: wake from deep sleep, read the sensors, connect to Wi-Fi, publish one MQTT message, disconnect, and return to deep sleep for approximately 300 s.

Parameter | Design value
MQTT transmission interval | 5 min (300 s)
MQTT messages per hour | 12
MQTT messages per day | 288
Battery arrangement | 1S2P — two 3500 mAh cells in parallel
Nominal battery voltage | 3.6–3.7 V
Nominal battery capacity | 7000 mAh
Nominal stored energy | 25.90 Wh
Regulated electronics rail | 3.3 V
GPS operation | Initialization only; OFF during normal monitoring

# 2. Component Power Data and Design Assumptions

The calculation uses manufacturer/datasheet values where available. Because the exact Wi-Fi association time, RF transmit duty cycle, thermistor resistance, and GPS model were not specified, a conservative engineering case is also included. The conservative case should be used for battery sizing.

Load | Value used | Basis
ESP8266 active/Wi-Fi interval | 100 mA for 5 s per cycle | Conservative design assumption; actual RF current varies
ESP8266 deep sleep | 20 µA | Espressif datasheet value
DHT11 measurement | 0.3 mA | DHT11 specification
DHT11 standby | 60 µA | DHT11 specification
Thermistor divider | 0.165 mA | 10 kΩ + 10 kΩ assumed at 3.3 V
3.3 V converter efficiency | 90% | Conservative engineering assumption
Converter quiescent current | 25 µA | Representative TPS63031 typical value

Espressif specifies an average operating current of about 80 mA for the ESP8266EX and reports 20 µA in deep sleep. Its RF section can draw substantially higher instantaneous current during transmission; the datasheet gives typical TX values of 120–170 mA depending on 802.11 mode. Espressif also gives a directly relevant example in which a temperature sensor sleeps for 300 s and then wakes to connect to the access point, with an overall average ESP8266 current below 1 mA.

# 3. Battery Configuration

Two 3500 mAh single-cell Li-ion batteries are selected in parallel, not in series. This produces a 1S2P pack: the voltage remains approximately 3.6–3.7 V nominal while the capacity becomes approximately 7000 mAh.

C_pack = 3500 mAh + 3500 mAh = 7000 mAh

E_pack ≈ 7.0 Ah × 3.7 V = 25.9 Wh

A protected 3500 mAh 18650 is a suitable cell class for this design. If unprotected Samsung INR18650-35E cells are used instead, a dedicated 1S protection/BMS circuit is mandatory. Cells connected in parallel should be matched, at similar state of charge, and from the same cell type/batch where practical. The protection and charging circuit must be designed for a 1S Li-ion pack with a 4.2 V charge limit.

# 4. Five-Minute MQTT Power Calculation

## 4.1 ESP8266 average current

Assume the ESP8266 is active for 5 s during each 300 s cycle at 100 mA. For the remaining 295 s it is in deep sleep at 20 µA = 0.020 mA.

I_ESP,avg = [(100 mA × 5 s) + (0.020 mA × 295 s)] / 300 s = 1.686 mA

## 4.2 DHT11 average current

The DHT11 is assumed to spend 1 s in its measurement state during each 5-minute cycle and to remain in its specified standby state for the rest of the interval.

I_DHT,avg = [(0.3 mA × 1 s) + (0.060 mA × 299 s)] / 300 s = 0.061 mA

## 4.3 Thermistor divider current

A 10 kΩ thermistor with a 10 kΩ fixed resistor is assumed for the analogue divider. At 3.3 V, the divider current is approximately:

I_divider = 3.3 V / (10 kΩ + 10 kΩ) = 0.165 mA

## 4.4 Total 3.3 V load

I_3V3,avg = 1.686 + 0.061 + 0.165 = 1.912 mA

The buzzer is assumed to be OFF during normal operation. The GPS is also excluded from the continuous load because it is powered only during location initialization.

## 4.5 Battery-side current through a buck-boost converter

A single-cell Li-ion battery cannot be regulated to 3.3 V over its complete discharge range by a simple AMS1117 LDO without losing usable battery capacity. A buck-boost converter is therefore recommended. For the calculation, 90% conversion efficiency is used.

I_bat,avg = (3.3 V × 1.912 mA) / (3.7 V × 0.90) + 0.025 mA = 1.920 mA

# 5. Battery Runtime

A practical design should not assume that every last milliamp-hour of the nominal battery capacity is usable. An 80% usable-capacity factor is applied to account for converter cutoff, cell voltage limits, temperature, ageing, and capacity tolerance.

C_usable = 7000 mAh × 0.80 = 5600 mAh

Runtime = 5600 mAh / 1.920 mA = 2917 h ≈ 121.5 days

Operating assumption | Average battery current | Estimated runtime
Conservative design case: 5 s active / 295 s deep sleep | 1.920 mA | 121.5 days
Espressif-style <1 mA ESP average + sensor loads | 1.240 mA | 188.2 days
No deep sleep; Wi-Fi maintained, ~15 mA modem-sleep baseline | 15.11 mA | 15.4 days

The large difference between the first and third cases is the key design result. Reducing the MQTT interval alone is not sufficient if the ESP8266 remains awake. The major battery-life improvement comes from putting the ESP8266 into deep sleep between measurements.

# 6. Daily Energy and Data Transmission

Quantity | Result
Messages per day | 288
Conservative average battery current | 1.920 mA
Approx. battery charge consumed per day | 46.1 mAh/day
Approx. nominal battery energy | 25.90 Wh
Approx. daily battery energy consumption | 0.170 Wh/day

At one MQTT message every 5 minutes, the node generates 12 messages per hour and 288 messages per day. This is generally adequate for environmental monitoring and reduces wireless activity by a factor of 300 compared with a one-message-per-second schedule.

# 7. GPS Initialization Energy

The GPS receiver is not part of the continuous power budget because it is used only to initialize the node location. As an engineering example, if a GPS receiver draws 50 mA for 60 s during initial acquisition, the one-time consumption is:

E_GPS,initial ≈ 50 mA × 1 h/60 = 0.83 mAh

This is negligible compared with a 7000 mAh battery. The exact GPS energy should nevertheless be recalculated using the selected receiver's datasheet and actual time-to-first-fix.

# 8. Regulator and Power-Path Recommendation

The existing AMS1117-3.3 arrangement should not be the preferred final power stage for a single-cell Li-ion battery. An LDO wastes the voltage difference as heat and, more importantly, cannot maintain 3.3 V once the cell voltage falls below the regulator's required headroom.

A buck-boost converter such as the TI TPS63031 is a suitable design reference because it accepts 1.8–5.5 V input, provides a fixed 3.3 V option, supports up to 500 mA in boost operation at 3.3 V, and has a typical quiescent current of 25 µA. The exact regulator should be selected after checking component availability, PCB layout requirements, and the ESP-12F's peak-current demand.

Power-stage item | Recommended implementation
Battery | 2 × 3500 mAh Li-ion, 1S2P, 3.6–3.7 V nominal
Protection | 1S Li-ion protection/BMS with overcharge, over-discharge and over-current protection
Regulator | 3.3 V buck-boost, ≥500 mA output capability preferred
ESP supply | 3.3 V regulated rail with local bulk + ceramic decoupling
DHT11 | 3.3 V supply; power-gate if further optimization is required
Thermistor | 10 kΩ divider; preferably switch divider power during deep sleep
GPS | Load-switched; ON only during initialization
Buzzer | Normally OFF
MQTT interval | 300 s
ESP sleep mode | Deep sleep between transmissions

# 9. Peak Current and Hardware Margin

Battery capacity determines runtime, but it does not guarantee reliable operation. The ESP8266 can draw much higher instantaneous current during Wi-Fi transmission than its long-term average. The power rail must therefore be designed for the peak load, not only the calculated average.

The ESP8266EX datasheet lists typical Wi-Fi TX currents of 120 mA for 802.11n, 140 mA for 802.11g, and 170 mA for 802.11b under specified test conditions. The regulator and PCB decoupling network should therefore provide adequate transient response. A practical design target is a regulated 3.3 V rail capable of at least 500 mA, with the exact margin verified experimentally.

# 10. Practical Battery-Life Optimization

• Use deep sleep rather than keeping the Wi-Fi association alive between MQTT transmissions.

• Power the GPS only during the initialization procedure and store the acquired location in non-volatile memory.

• Switch off the thermistor divider during deep sleep if the firmware/hardware permits it; this removes the continuous 0.165 mA divider current.

• Use a buck-boost regulator instead of AMS1117-3.3 for the final single-cell design.

• Avoid indicator LEDs that remain continuously powered; their current can become significant relative to the deep-sleep load.

• Place low-ESR bulk capacitance and ceramic decoupling close to the ESP-12F power pins to handle Wi-Fi current transients.

• Use matched cells in the 1S2P battery pack and provide proper 1S protection and charging.

• Validate the theoretical runtime using an ammeter/data logger because Wi-Fi retry time and access-point signal strength can dominate the actual wake energy.

# 11. Engineering Conclusion

For the proposed temperature-monitoring node, changing the MQTT interval to 5 minutes and using two 3500 mAh cells in a 1S2P arrangement gives a 7 Ah, approximately 25.9 Wh nominal battery pack. With deep sleep between transmissions, the calculated conservative battery-side average current is approximately 1.92 mA, giving an estimated runtime of about 122 days after applying an 80% usable-capacity factor. The actual runtime can be higher or lower depending primarily on Wi-Fi connection time, RF retries, regulator efficiency, sensor powering strategy, and battery condition.

If the ESP8266 is kept awake instead of using deep sleep, the same battery is expected to last only on the order of 15 days under the simplified 15 mA modem-sleep baseline. Therefore, deep sleep is the principal design requirement for achieving a genuinely long-lasting 5-minute MQTT node.

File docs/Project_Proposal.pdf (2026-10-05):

# IoTRiX 2.0

T R A C K C · P R O J E C T P R O P O S A L

# Smart Grain Storage and Mushroom Monitoring System

### A distributed, low-cost IoT platform for continuous temperature and relative humidity

monitoring in Sri Lankan grain storage houses and mushroom cultivation rooms.

T E A M N A M E : S I S Y P H U S

T E A M M E M B E R S :

### J.J.K. Pooja S. Juththis S. Kishown S. Aksaraan

Smart Grain Storage and Mushroom Monitoring System | Team Sisyphus | IoTRiX 2.0
Project Proposal · Track C | Page ii

# Table of Contents

Executive Summary | 1
1 Introduction and Background | 1
2 Problem Statement | 1
3 Aim and Objectives | 2
4 Scope of the Project | 2
5 Proposed Methodology | 3
6 Current Progress and Validation Plan | 6
7 Work Plan and Project Management | 7
8 Resources and Budget | 8
9 Risks and Mitigation | 10
10 Expected Outcomes and Significance | 10
11 Future Development | 10
12 Conclusion | 11
References | 11

## List of Figures and Tables

Figure 5.1: Proposed System Architecture and Development Boundaries | 3
Figure 5.2: Node-Level Processing and System Data Flow | 5
Table 5.1: Hardware Functions | 3
Table 6.1: Current Development Progress | 6
Table 6.2: Testing and Evaluation Plan | 6
Table 7.1: Implementation Milestones | 7
Table 8.1: Prototype Bill of Materials | 8
Table 8.2: Budget for One Final-Product Unit | 9
Table 9.1: Risks and Proposed Mitigation | 10

## Executive Summary

The Smart Grain Storage and Mushroom Monitoring System proposes an affordable, distributed Internet of Things (IoT) platform for monitoring temperature and relative humidity in Sri Lankan grain storage houses and mushroom cultivation rooms. Multiple sensing locations will provide operators with a clearer view of environmental variation and support timely action when conditions move outside application-specific limits.

Each wireless node uses an ESP32, a DHT11 temperature and relative humidity sensor, and an NTC thermistor. The temperature measurements are processed using Weighted Least Squares (WLS) fusion followed by Kalman filtering. Telemetry is transmitted over Wi-Fi using MQTT to a centralized Node-RED dashboard. The platform will support separate grain storage and mushroom monitoring configurations, with dashboard warnings and local buzzer alerts.

The current proof of concept comprises two operational nodes, each with two temperature sensors, and a working sensing-to-dashboard communication path. A custom PCB and enclosure have been designed; fabrication, full electrical validation, buzzer integration, and application-specific condition assessment remain to be completed. The proposal sets out the methodology, validation activities, implementation milestones, resource requirements, and risks involved in developing the prototype into a deployable system.

## 1 Introduction and Background

Grain storage and mushroom cultivation require environmental observations that reflect conditions across the monitored space. A reading taken at one location or during an occasional inspection may not represent changes elsewhere in a storage house or growing room. A distributed monitoring system can make these variations visible and provide a continuous record for operational decisions. In stored grain this matters because cereals conduct heat poorly, so local temperature changes and hot spots can remain confined to part of the store. Grain degradation depends mainly on temperature, moisture and oxygen, and the safe moisture level falls as temperature rises; storage fungi require a relative humidity of at least about 65% and grow at roughly 10–40 °C.

For Sri Lankan grain storage houses, the proposed approach uses accessible sensing locations across relevant storage zones. For mushroom cultivation, nodes can be placed in different growing areas or racks. The same hardware platform can serve both applications through different threshold configurations, reducing the need to develop two separate systems.

This proposal focuses on the end-to-end system architecture, sensing and processing method, custom hardware, dashboard, deployment process, and engineering validation relevant to an IoT product submission under Track C. Wireless nodes avoid cabling and give real-time access to readings, so abnormal conditions can be detected and acted on promptly; low-cost wireless sensors have been used in this way in other settings, such as preventive conservation in museums.

## 2 Problem Statement

Operators need a practical way to identify unsuitable temperature and relative humidity conditions across multiple locations. Periodic manual observations and isolated measurements offer limited visibility of how conditions vary with location and time. This can delay recognition of environmental conditions associated with grain deterioration or unsuitable mushroom cultivation conditions.

The engineering problem is therefore to develop an affordable multi-node platform that acquires dependable measurements, communicates them reliably, and presents application-specific warnings. The system must also distinguish sensor or communication faults from environmental warnings and remain accessible for installation and maintenance.

## 3 Aim and Objectives

### 3.1 Project aim

To develop and validate a modular IoT system for continuous, multi-point temperature and relative humidity monitoring in grain storage and mushroom cultivation environments.

### 3.2 Specific objectives

### 1. Develop ESP32 sensing nodes with DHT11 and NTC temperature measurements and DHT11

relative humidity acquisition.

2. Calibrate and evaluate the temperature sensors, implement WLS fusion and Kalman filtering, and compare the processed estimate with reference measurements.
3. Provide Wi-Fi and MQTT telemetry to a Node-RED dashboard with unique node identification and connectivity reporting.

### 4. Implement and validate separate application thresholds, NORMAL, WARNING, and CRITICAL

states, and local and dashboard alerts.

### 5. Fabricate and validate the custom PCB, integrate the enclosure, and assess deployment

practicality, power consumption, and communication reliability.

## 4 Scope of the Project

The current development scope covers the two-node prototype, temperature and relative humidity sensing, edge processing, wireless telemetry, dashboard integration, application configuration, buzzer alerts, and the transition to custom PCB and enclosure hardware. Further nodes may be added after the two-node system is validated.

GPS and the OLED are development aids. The deployed configuration will omit the OLED and retain only temporary GPS connectivity for position initialization where usable. The project does not include direct fungal detection, automated climate control, or current CO₂ measurement. Application thresholds, battery life, field performance, and a maximum supported node count will be established through validation rather than assumed.

## 5 Proposed Methodology

### 5.1 System architecture

The system is organized into three operational layers: distributed sensing and edge processing, Wi-Fi and MQTT communication, and centralized monitoring. Each node acquires and processes measurements locally before publishing structured telemetry. The dashboard associates incoming data with a unique node and its configured application. Figure 5.2 in Section 5.5 shows the node-level detail.

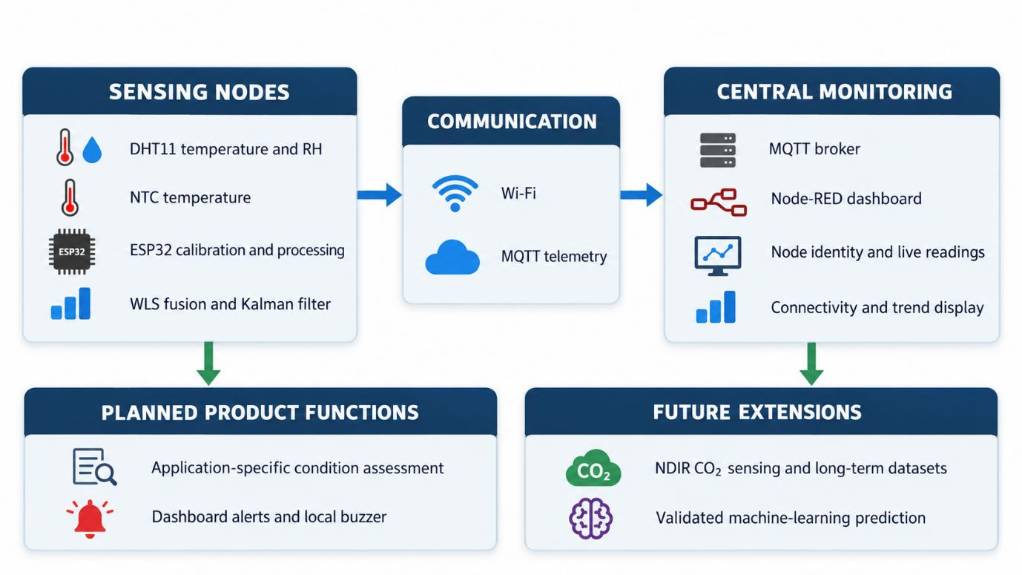
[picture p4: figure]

Figure 5.1: Proposed System Architecture and Development Boundaries

### 5.2 Sensing hardware and product integration

Table 5.1: Hardware Functions

Component | Function and interface
ESP32 | Controller for sensor acquisition, processing, Wi-Fi, and telemetry.
DHT11 | Digital temperature and relative humidity measurement.
NTC thermistor | Independent temperature measurement through the ESP32 ADC.
Buzzer | GPIO-controlled local alert in the final configuration.
Custom PCB and power circuitry | Integration of the controller, sensors, alert, power, and temporary GPS interface.
Enclosure | Mechanical protection, mounting, ventilation, and access for maintenance.
NEO-6M GPS and OLED | Temporary UART GPS support and an I²C prototype display; not continuous deployed features.

The PCB and enclosure designs are coordinated around the ESP32 platform. The enclosure must allow sensor exposure, ventilation, connector access, buzzer operation, and maintenance. Published sensor-node designs show why ventilation matters: air must exchange freely between the housing interior and the room so that the sensor tracks local conditions, using a large aperture and no humidity-absorbing material inside the housing to shorten response time. Where a 3-D printed enclosure is used, material choice should take into account that PLA deformed and degraded under outdoor heat and UV exposure while ASA performed better. Fabrication and physical validation remain pending.

### 5.3 Sensor processing and conditioning assessment

The node acquires temperature from the DHT11 and NTC thermistor, applies calibration, checks validity, and rejects abnormal measurements. Valid readings are combined using WLS, with relative weights based on experimentally determined measurement uncertainty. The fused result is then processed with a Kalman filter to reduce short-term fluctuation while retaining the underlying trend. DHT11 relative humidity is acquired separately.

Fusion and filtering performance will be evaluated against the individual calibrated sensors. The use of two temperature sensors does not by itself establish higher accuracy; the validation must demonstrate the effect of calibration, weighting, and filtering over representative operating conditions.

In Grain Storage Mode, the proposed condition logic evaluates temperature, relative humidity, and the duration of unfavorable conditions to assign NORMAL, WARNING, or CRITICAL status. In Mushroom Monitoring Mode, the limits depend on the selected mushroom type and cultivation stage. Referenced threshold values and persistence rules must be documented before final validation. For Grain Storage Mode, FAO guidance will be the starting reference: it identifies equilibrium with air at 65–70% relative humidity as the safe condition for long-term storage and relates the permissible storage duration to both temperature and grain moisture content. Environmental warnings indicate a need for inspection or action. They are not confirmation of fungal growth or mycotoxin contamination, which FAO notes can only be established by laboratory examination.

### 5.4 Communication and dashboard

Nodes publish structured telemetry through Wi-Fi to an MQTT broker, which supplies the Node-RED dashboard. MQTT telemetry to a cloud dashboard has also been used in low-cost open-source environmental sensing hardware. The monitoring interface is intended to show node identity, fused temperature, relative humidity, connectivity, application mode, condition status, live readings, trends, and alarms. Location labels support identification of the corresponding storage zone or growing area.

Reliability work will address Wi-Fi and MQTT reconnection, sensor validity checks, invalid-data rejection, and node connectivity reporting. Temporary buffering during network loss and over-the-air firmware updates are planned improvements. Practical scalability will be assessed using node count, reporting interval, message size, network coverage, broker capacity, and available power. Wi-Fi operates in the 2.4 GHz band, which can struggle over long distances and through thick walls , so coverage will be surveyed at each site before installation.

### 5.5 Deployment and operation

For grain storage, nodes will be installed at accessible locations representing different storage zones. For mushroom cultivation, locations will represent selected growing zones or racks. Each installation will receive a node ID, a location record, an application mode, and a documented threshold configuration.

Commissioning will proceed through mounting, identification, configuration, network connection, MQTT verification, and dashboard verification before monitoring begins. The prototype GPS supports position initialization where a usable fix is available; reliable indoor GPS positioning is not assumed. The OLED supports development checks and demonstrations and will be removed from the deployed product to reduce hardware cost and power demand.

Figure 5.2 summarizes the complete data flow: the processing performed inside each node, transmission over Wi-Fi and MQTT to the broker and Node-RED, and the application-specific condition assessment that produces the NORMAL, WARNING, or CRITICAL status.

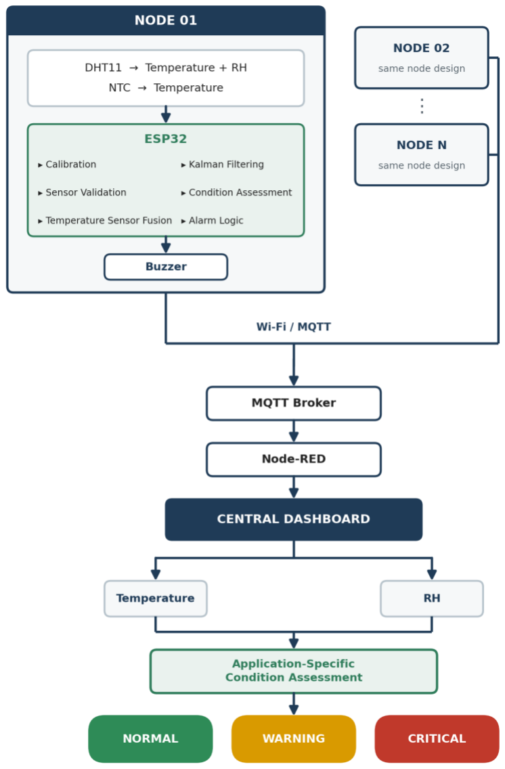
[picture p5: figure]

Figure 5.2: Node-Level Processing and System Data Flow

## 6 Current Progress and Validation Plan

### 6.1 Current development status

Table 6.1: Current Development Progress

Stage | Present position
Demonstrated or operational | Two sensing nodes; DS18B20 temperature; NTC temperature; WLS fusion; Kalman filtering; Wi-Fi and MQTT; Node-RED dashboard; GPS and OLED development support.
Designed | Custom schematic, routed PCB, 3D PCB representation, enclosure, and final node architecture.
Under development | Buzzer integration, DHT11 integration and calibration, application thresholds and condition logic, PCB fabrication, electrical validation, and deployment validation.
Planned extensions | OTA evaluation, stronger reconnection handling, power characterization, long-duration tests, and broader node deployment.

The prototype demonstrates the end-to-end data path. Quantitative accuracy, latency, reliability, operating duration, and field-performance results remain to be established through the validation plan below.

### 6.2 Testing and evaluation

Table 6.2: Testing and Evaluation Plan

Validation area | Method and evidence to record
Sensing and processing | Compare DHT11, NTC, fused, and filtered temperature with a reference. Record calibration, error, variability, and response to temperature changes; verify RH readings.
Condition logic and alerts | Apply test values below, near, and above each selected threshold. Verify duration rules, state transitions, dashboard warnings, and buzzer response.
Communication and dashboard | Verify two-node identification, publishing and reception, update delay, disconnections, reconnection, missing data, and displayed values.
PCB and enclosure | Check the fabricated power and signal paths; test sensor interfaces and buzzer; verify assembly, ventilation, connector access, and mounting.
Power and field operation | Measure consumption and operating duration; run longer tests in representative grain storage and mushroom environments.

Test logs, plots, photographs, firmware versions, and identified issues will be retained with the project documentation. Acceptance limits will be defined before the corresponding tests, and completed results will be distinguished from planned activities. Communication reliability will be reported as the proportion of transmitted messages received together with signal strength, as in field evaluations of wireless environmental sensors , and sensing accuracy will be assessed against a reference instrument and an unprotected sensor, as in sensor-shield validation studies.

## 7 Work Plan and Project Management

### 7.1 Implementation milestones

Work will proceed through the following milestones. The sequence identifies dependencies; calendar dates will be finalized against the competition schedule, component availability, and PCB fabrication lead time.

Table 7.1: Implementation Milestones

Milestone | Activities | Completion evidence
Finalize requirements | Select and reference application thresholds; define validation limits and alert behavior. | Approved configuration and test plan.
Complete firmware and alerts | Integrate buzzer and application modes; strengthen sensor checks and reconnection handling. | Bench results for sensing, states, and alarms.
Realize product hardware | Fabricate and inspect the PCB; assemble and electrically validate it; fit the enclosure. | Working assembled node and hardware records.
Validate the integrated system | Evaluate sensing, communications, dashboard, power, and longer-duration operation. | Recorded results and resolved fault list.
Conduct representative trials | Install accessible nodes in target environments; evaluate operation and deployment practicality. | Field observations and remaining limitations.
Prepare final submission | Consolidate evidence, documentation, demonstration, and repository. | Traceable technical package and demonstration.

### 7.2 Project coordination and documentation

Work will be organized across embedded firmware, hardware and mechanical integration, dashboard and communication, and testing and documentation. Named responsibilities and milestone dates will be recorded in the project management documentation.

The GitHub repository will retain the architecture, schematics, PCB and mechanical files, firmware, dashboard flows, communication specification, bill of materials, test data, results, and project documentation. Changes will be committed progressively so that the development history and the tested configurations remain traceable.

The main documentation areas will be docs, hardware, firmware, dashboard, communication, data, results, and project management. Hardware records will include the schematic, PCB, enclosure, and BOM. Demonstration evidence will link the operational nodes to the displayed telemetry and the corresponding firmware revision.

### 7.3 Final demonstration

The demonstration will show two distinguishable nodes publishing temperature to the dashboard. Completed alert functions will be demonstrated with controlled input conditions. The presentation will distinguish operational features, designed hardware, validation still in progress, and future extensions.

## 8 Resources and Budget

The platform uses one shared hardware design for both applications, built from commonly available embedded components. All costs are in Sri Lankan rupees (Rs). Section 8.1 records the prototype bill of materials, while Section 8.2 updates the final-product budget using the supplied final PCB BOM. Costs not included in that BOM are clearly identified as TBC.

### 8.1 Prototype bill of materials

Table 8.1: Semi-final Prototype Bill of Materials

Item | Component | Specification | Qty | Unit cost (Rs) | Total (Rs)
1 | ESP32 Dev module | ESP32 Wi-Fi/Bluetooth
| | development board | 1 | 1500.00 | 1500.00
2 | DS18B20 Temperature
| Sensor | Digital 1-Wire
| | temperature sensor | 1 | 160.00 | 160.00
3 | NTC Thermistor | MF5A-3, 10 kΩ, B3950 | 1 | 60.00 | 60.00
4 | GPS Module | NEO-6M GPS module | 1 | 2490.00 | 2490.00
5 | OLED Display | SSD1306, 128 × 64, I2C,
| | 0.96 in | 1 | 940.00 | 940.00
6 | N-Channel MOSFET | IRLZ44N | 2 | 95.00 | 190.00
7 | Push Button | Momentary push button | 1 | 45.00 | 45.00
8 | Fixed Resistor | 10 kΩ, for NTC voltage
| | divider | 1 | 5.00 | 5.00
9 | Pull-up Resistor | 4.7 kΩ, for DS18B20
| | DATA line | 1 | 5.00 | 5.00
10 | MOSFET Gate Resistor | 220 Ω | 2 | 3.00 | 6.00
11 | MOSFET Gate Pull-
| down Resistor | 100 kΩ | 2 | 6.00 | 12.00
12 | 1S Battery Holder | Single-cell battery holder | 1 | 40.00 | 40.00
13 | Rechargeable Battery | 1800 mAh 3.7 Li-ion
| | Cell | 1 | 400.00 | 400.00
14 | Soldering Iron Lead | For soldering | | Free | -
15 | Single core Cu wire | For connections | 2m | 45.00 | 90.00
16 | 10x24 Dot board | Mounting components | 1 | 200.00 | 200.00
| | | | TOTAL COST | 6143.00

The prototype total of Rs 6,143.00 includes Rs 3,720.00 of items that are not part of the final unit: the NEO-6M GPS module and SSD1306 OLED display, which are development aids, and the wire and dot board used for hand wiring.

### 8.2 Budget for one final-product unit

Table 8.2: Budget for One Final-Product Unit

Component | Specification | Qty | Unit cost (Rs) | Total (Rs)
Capacitor | 10 µF, through-hole | 2 | 5.00 | 10.00
Capacitor | 100 nF, through-hole | 1 | 2.00 | 2.00
4-pin connector | HC-EH2.54-4A-TW | 1 | 40.00 | 40.00
JST connector | JST-PH-2-SMT-RA | 1 | 20.00 | 20.00
5-pin header | 2.54 mm, 1×5 | 2 | 6.00 | 12.00
N-Channel MOSFET | IRLZ44PBF / TO-220 | 1 | 95.00 | 95.00
10 kΩ resistors | Through-hole | 7 | 1.50 | 10.50
100 Ω resistor | Through-hole | 1 | 1.50 | 1.50
Push buttons | 4.5×4.5×3.8 mm tactile switch | 2 | 18.00 | 36.00
ESP-12F module | 2.4 GHz Wi-Fi module | 1 | 660.00 | 660.00
2-pin jumper header | 2.54 mm | 1 | 5.00 | 5.00
Voltage regulator | AMS1117-3.3 | 1 | 20.00 | 20.00
NTC thermistor | 10 kΩ | 1 | 60.00 | 60.00
Buzzer | HX-2212 local alert buzzer | 1 | 55.00 | 55.00
DHT11 sensor | Temperature and relative humidity sensor | 1 | 230.00 | 230.00
Rechargeable battery / power source | 3500 mAh Li-ion | 2 | 690 | 1380.00
Custom PCB fabrication | Board fabrication cost | 1 | TBC | TBC
3-D printed enclosure | Final mechanical enclosure | 1 | TBC | TBC

Component | Specification | Qty | Unit cost (Rs) | Total (Rs)
CONFIRMED PCB ELECTRONICS SUBTOTAL | | | | 2,625.00
TOTAL PER UNIT | | | | Rs 2,625.00
| | | | +PCB
| | | | fabrication +
| | | | enclosure

Based on the supplied final PCB bill of materials, the confirmed electronic component cost for one unit is Rs 1,245.00. This figure includes the ESP-12F module, DHT11 sensor, NTC thermistor, buzzer, voltage regulator, MOSFET, switches, connectors, capacitors, resistors, and headers used on the final board. The battery or other power source, PCB fabrication, and 3-D printed enclosure are not priced in the supplied BOM and are therefore shown as TBC until their final quotations are available.

The final per-node deployment cost will therefore be the confirmed Rs 1,245.00 electronics BOM plus the selected battery/power source, PCB fabrication, and enclosure costs. A deployment with N nodes will scale approximately with the number of nodes, while shared infrastructure such as Wi-Fi access, the MQTT broker, and the Node-RED host is counted separately where it is not already available.

## 9 Risks and Mitigation

Table 9.1: Risks and Proposed Mitigation

Risk or limitation | Proposed mitigation
Unvalidated application thresholds | Select referenced limits for each application and verify state and duration rules before field use.
Sensor bias or invalid readings | Calibrate, compare with a reference, validate fusion, and flag rejected or failed measurements.
Wi-Fi or broker interruption | Test reconnection and missing-node reporting; evaluate temporary buffering.
Fabrication or assembly issues | Review the design, inspect fabricated boards, and perform electrical checks before enclosure integration.
Uncharacterized power demand | Measure operating consumption and establish achievable operating duration.
Limited field evidence and node count | Expand beyond the two-node demonstration only after longer, representative tests.

## 10 Expected Outcomes and Significance

The immediate outcome will be a validated two-node monitoring system with documented temperature processing, relative humidity acquisition, MQTT telemetry, and a centralized dashboard. The product development work is expected to deliver fabricated and tested PCB hardware, integrated enclosures, configurable condition assessment, and local and dashboard alerts.

The proposed value lies in combining distributed measurements, two temperature sensing methods, local processing, and a shared monitoring interface within a modular platform. Separate application configurations will allow the same core hardware to serve grain storage houses and mushroom growing rooms. Accessible mounting and replaceable components will support practical maintenance.

The intended benefit is improved visibility of environmental conditions and earlier recognition of unsuitable conditions. Reductions in spoilage, improvements in yield, and economic savings will require field evidence and are not claimed as established outcomes. The validation records will determine which performance claims can be made for the final system.

## 11 Future Development

### 11.1 Carbon dioxide monitoring

A later version may add a dedicated non-dispersive infrared (NDIR) CO₂ sensor to measure concentration in parts per million. This would extend the environmental data available for grain storage and mushroom cultivation assessments. Sensor selection, calibration, placement, cost, and application interpretation will require separate evaluation. CO₂ monitoring is outside the current prototype scope.

### 11.2 Historical data and predictive analysis

Long-term data storage will support trend analysis and the development of application-specific datasets. Candidate records include temperature, relative humidity, timestamps, node identity, location, application mode, condition status, and verified observations of grain quality or mushroom growth. Future CO₂ measurements may be added once sensing is implemented.

Machine-learning prediction will be considered only after sufficient representative and correctly labelled data are available. Until then, transparent threshold-based logic provides the basis for condition assessment. Further development may also extend node deployment, local buffering, and validated OTA maintenance.

## 12 Conclusion

The proposed system provides a practical development path from an operational two-node IoT demonstration to an integrated environmental monitoring product. The next stage will focus on application-specific assessment, alerts, fabricated hardware, reliable communication, and representative validation. Completing these activities will provide the evidence needed to assess deployment readiness and the feasibility of a reusable monitoring platform for Sri Lankan grain storage and mushroom cultivation.

## References

[1] Food and Agriculture Organization of the United Nations (FAO), “The fundamentals of storage,” in Manual of the Prevention of Post-Harvest Grain Losses, ch. 2. [Online]. Available: https://www.fao.org/4/x5065e/x5065e04.htm (accessed Oct. 4, 2026).
[2] FAO, “Storage,” in Agricultural Engineering in Development. [Online]. Available: https://www.fao.org/4/t0522e/T0522E09.htm (accessed Oct. 4, 2026).

[3] FAO, “Fungi and mycotoxins,” in Manual of the Prevention of Post-Harvest Grain Losses, ch.
6. [Online]. Available: https://www.fao.org/4/x5065e/x5065E0c.htm (accessed Oct. 4, 2026).
[4] J. Laborda, A. M. García-Castillo, R. Mercado, A. Peiró-Vitoria, and A. Perles, “From concept to validation of a wireless environmental sensor for the integral application of preventive conservation methodologies in low-budget museums,” Heritage Science, vol. 10, art. no. 197, 2022, doi: 10.1186/s40494-022-00837-9.
[5] Espressif Systems, “ESP32 Series Datasheet.”
[6] J. S. Botero-Valencia, M. Mejia-Herrera, and J. M. Pearce, “Design and implementation of 3-D printed radiation shields for environmental sensors,” HardwareX, vol. 11, art. no. e00267, 2022, doi: 10.1016/j.ohx.2022.e00267.
[7] Aosong Electronics Co., Ltd., “DHT11 Humidity and Temperature Sensor Datasheet.”
[8] R. E. Kalman, “A new approach to linear filtering and prediction problems,” Journal of Basic Engineering, vol. 82, no. 1, pp. 35–45, 1960.
[9] OASIS, “MQTT Version 3.1.1,” OASIS Standard, Oct. 2014.

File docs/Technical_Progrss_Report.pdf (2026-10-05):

# SMART GRAIN & MUSHROOM MONITORING SYSTEM

## PROJECT PURPOSE

🌾
🍄

Continuously monitor spatial variations in temperature, relative humidity at multiple locations; identify unfavorable conditions early; provide local + centralized warnings; and store telemetry for future analysis and validated predictive modelling.

## HOW THE SYSTEM WORKS

🌾🍄

ENVIRONMENT

Grain store / mushroom room

→ 🌡💧

SENSOR NODE

DHT11 + NTC

→ | ⚙

EDGE PROCESS

Validate • fuse • filter

→ 📡

MQTT

Wi-Fi telemetry

→ 🖥

NODE-RED

Dashboard + alerts

## WHAT EACH SMART NODE DOES

🌡

Temperature + Humidity
DHT11 + NTC
sensor fusion

📡

Connectivity
Wi-Fi + MQTT
node status

🔔Local alert

Buzzer warning

📍

Location
Temporary GPS
initialization

## PROCESSING + EARLY-WARNING LOGIC

RAW DATA | → | CALIBRATE +
VALIDATE | → | WLS FUSION +
KALMAN FILTER | → | FUSED T + RH
NORMAL | → | LIMITS + TRENDS +
NODE STATUS | → | WARNING /
CRITICAL | → | BUZZER +
DASHBOARD ALERT

## APPLICATION MODES & IMPORTANT ENGINEERING FACTS

🌾 GRAIN STORAGE MODE

- Tracks conditions associated with moisture-related
deterioration.
- Provides environmental-risk indication.

🍄 MUSHROOM MODE

- Checks whether temperature remain within selected cultivation ranges.
- Uses stage/application-specific thresholds.

⚠ SENSOR INTERPRETATION

- Thresholds must be documented from research and technical guidance.

## CURRENT PROGRESS & TECHNOLOGY STACK

✓ CURRENTLY WORKING / VALIDATED

- Two operational wireless sensing nodes connected to a centralized Node-RED dashboard.
- DS18B20 temperature + NTC temperature acquisition working.
- Temperature calibration, validation, outlier rejection, WLS fusion and Kalman filtering architecture established.
- Wi-Fi/MQTT live telemetry and multi-node dashboard visualization demonstrated.
- OLED + NEO-6M GPS retained for prototype development/testing only.

⚙ TECHNOLOGY STACK

- Hardware: ESP32, DHT11, NTC, buzzer, temporary GPS, prototype OLED, power management.
- Final hardware: custom PCB + enclosure; OLED removed; GPS used only when location initialization is required.
- Embedded: calibration, validity checks, outlier rejection, WLS, Kalman filtering, condition logic, alarm control.
- Communication/monitoring: Wi-Fi, MQTT, structured telemetry, Node-RED, trends, logging and alerts.

## VALIDATION, LIMITATIONS & TECHNICAL RISKS

🧪 SYSTEM VERIFICATION & DEVELOPMENT STATUS

- Completed: sensing, wireless telemetry, dashboard display and temperature-processing chain.
- In progress: buzzer integration, Improving threshold validation, PCB/enclosure integration.
- Required: long-duration field tests, representative grain/mushroom trials, network-loss recovery, power/battery characterization.

⚠ LIMITATIONS / RISKS

- Wi-Fi availability may interrupt live communication; robust reconnection is required.
- Final thresholds, large-scale multi-node behavior and custom PCB performance still require validation.

## NEXT DEVELOPMENT MILESTONE

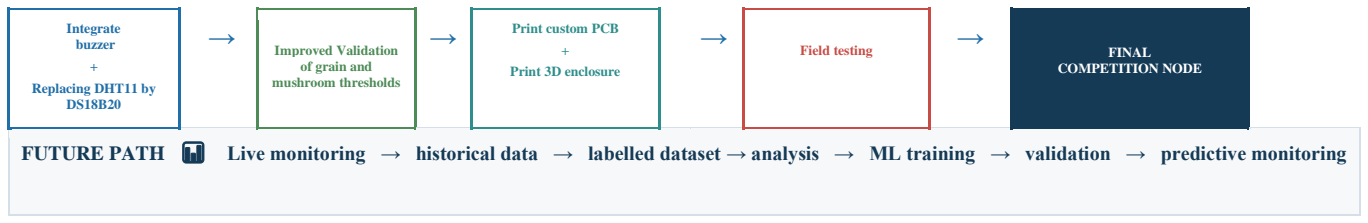
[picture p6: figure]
Integrate buzzer; Replacing DHT11 by DS18B20; Improved Validation; of grain and mushroom thresholds; Print custom PCB; Print 3D enclosure; Field testing; FINAL; COMPETITION NODE

FUTURE PATH 📊 Live monitoring → historical data → labelled dataset → analysis → ML training → validation → predictive monitoring

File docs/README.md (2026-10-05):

# Documentation

This folder contains the main technical and competition-related documentation for the Smart Grain Storage and Mushroom Monitoring System.

The documents in this section are intended to provide a clear overview of the project concept, system architecture, current development progress, testing evidence, and planned improvements.

## Contents

This folder includes:

- IoTrix 2.0 Project Proposal
- One-Page Technical Progress Sheet
- System Architecture Diagram
- Testing and Validation Summary
- Supporting figures and project images

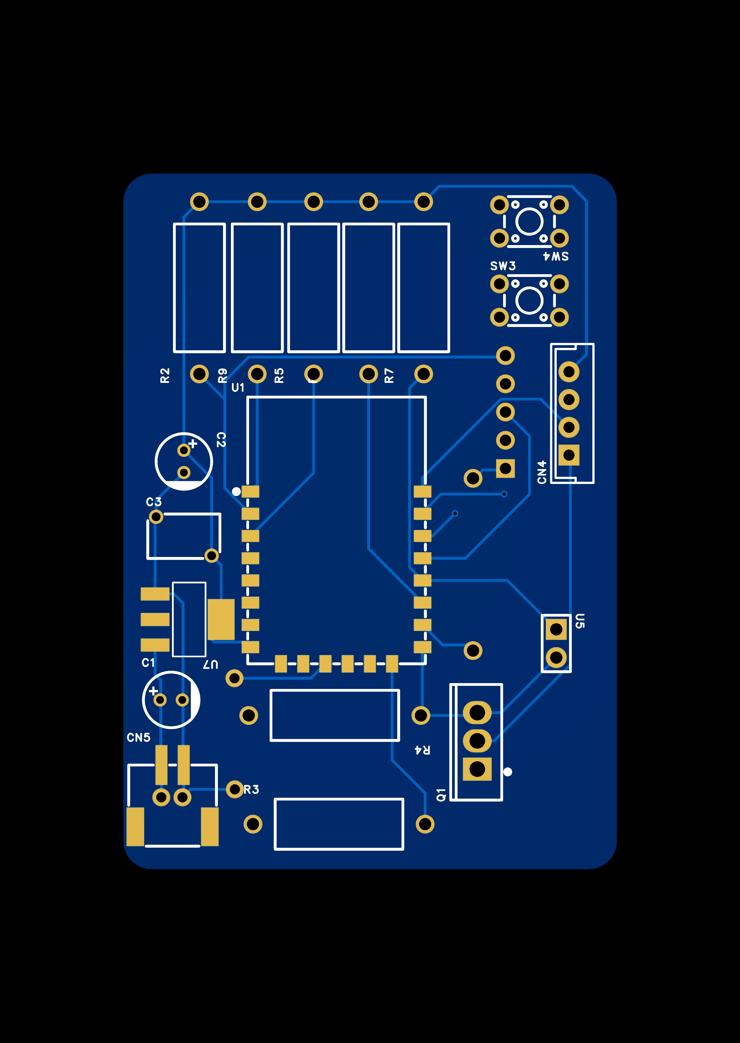
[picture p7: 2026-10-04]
hardware/pcb/microcontroller_pcb/top_layer.png

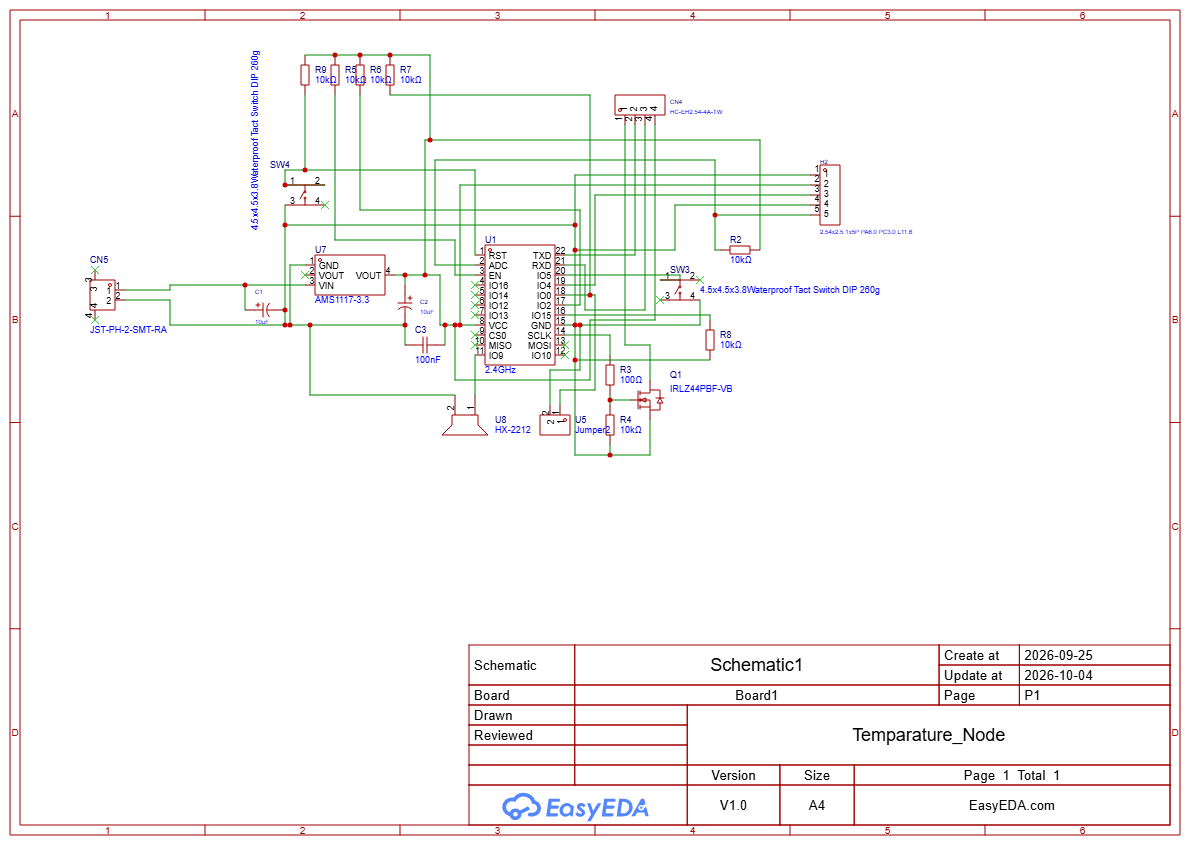
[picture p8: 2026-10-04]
hardware/schematic/microcontroller_Schematic.png

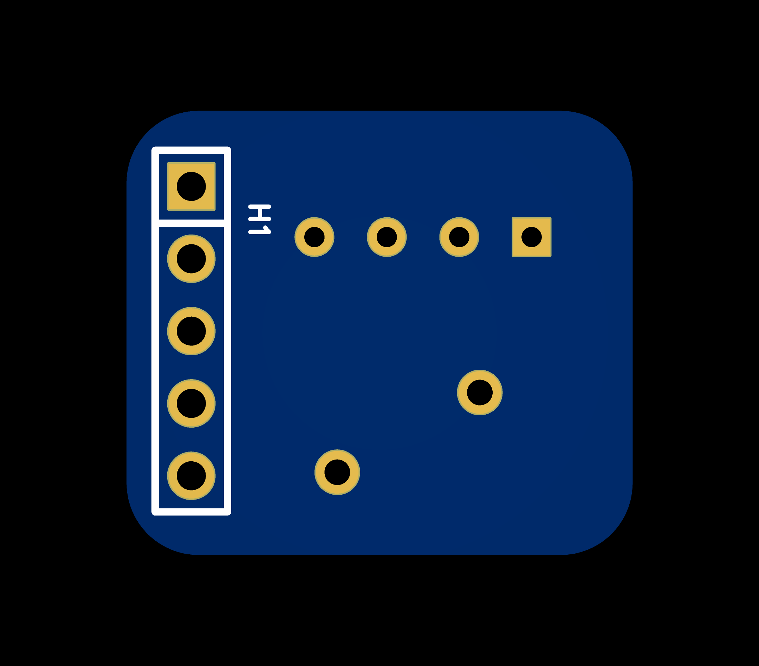
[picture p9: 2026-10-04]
hardware/pcb/sensor_holder_pcb/bottom_layer.png

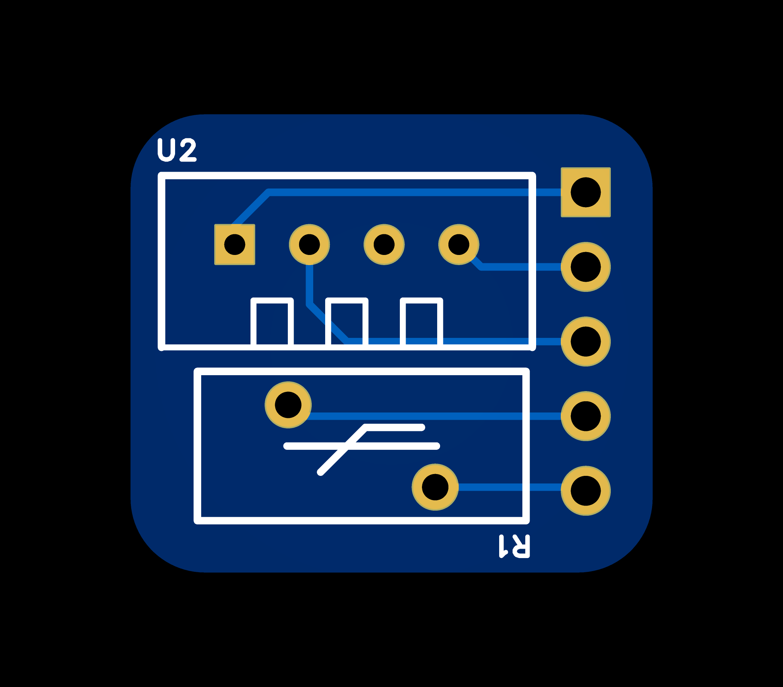
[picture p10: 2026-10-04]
hardware/pcb/sensor_holder_pcb/top__layer.png

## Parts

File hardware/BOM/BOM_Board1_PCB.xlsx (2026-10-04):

No. | Quantity | Comment | Designator | Footprint | Value | Unit Price (LKR) | Total Price (LKR)
1 | 2 | 10uF | C1,C2 | CAP-TH_BD5.0-P2.00-D0.5-FD_H11.0 | 10uF | 5 | 10
2 | 1 | 100nF | C3 | CAP-TH_L6.5-W4.0-P5.00-D0.5-LS3.50 | 100nF | 2 | 2
3 | 1 | HC-EH2.54-4A-TW | CN4 | CONN-TH_4P-P2.50_HC-EH2.54-4A-TW |  | 40 | 40
4 | 1 | JST-PH-2-SMT-RA | CN5 | CONN-SMD_JST-PH-2-SMT-RA |  | 20 | 20
5 | 2 | 2.54x2.5 1x5P PA6.0 PC3.0 L11.6 | H2 | HDR-TH_5P-P2.54-V-M-3 |  | 6 | 12
6 | 1 | IRLZ44PBF-VB | Q1 | TO-220AB-3_L10.4-W4.6-P2.54-L |  | 95 | 95
7 | 7 | 10kΩ | R2,R4,R5,R6,R7,R8,R9 | RES-TH_BD4.5-L11.5-P15.50-D0.8 | 10kΩ | 1.5 | 10.5
8 | 1 | 100Ω | R3 | RES-TH_BD4.5-L11.5-P15.50-D0.8 | 100Ω | 1.5 | 1.5
9 | 2 | 4.5x4.5x3.8Waterproof Tact Switch DIP 260g | SW3,SW4 | SW-TH_4P-L4.5-W4.5-P3.00-LS5.4 |  | 18 | 36
10 | 1 | 2.4GHz | U1 | WIRELM-SMD_ESP-12F | 2.4GHz | 660 | 660
11 | 1 | Jumper2 | U5 | HDR-TH_2P-P2.54-V-M-1 |  | 5 | 5
12 | 1 | AMS1117-3.3 | U7 | SOT-223-3_L6.5-W3.4-P2.30-LS7.0-BR |  | 20 | 20
13 | 1 | NTC2.5D-9SMFSOE | R1 | RES-TH_L11.0-W5.5-P5.00-D0.6-S2.80 | 10kΩ | 60 | 60
14 | 1 | Buzzer | U8 | HX-2212 |  | 55 | 55
14 | 1 | DHT11 | U2 | SENSOR-TH_DHT11 |  | 230 | 230
 |  |  |  |  |  |  | 1245

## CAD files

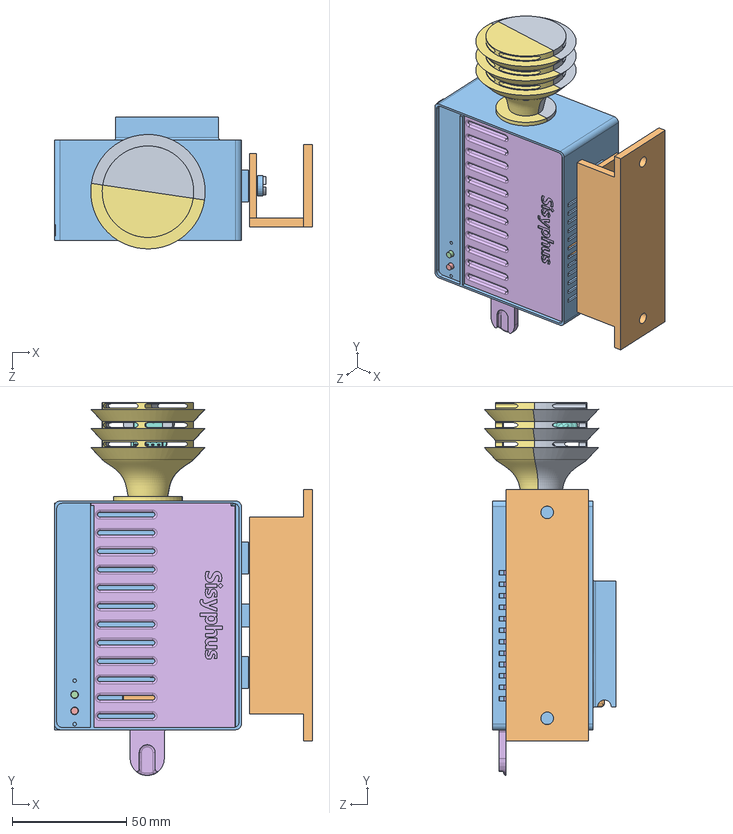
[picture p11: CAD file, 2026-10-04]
hardware/mechanical/model/assembly/Node enclosure.SLDASM
112.9 x 163.0 x 57.6 mm
Main body
Li-iron Battery 1000mAh
sensor holder 2
RH,Tem sensor
sensor holder
Buttons_closer
Button plunger 1
Button plunger 2
Button_retainer
Side wall hanger
Hanger lock screw envelope

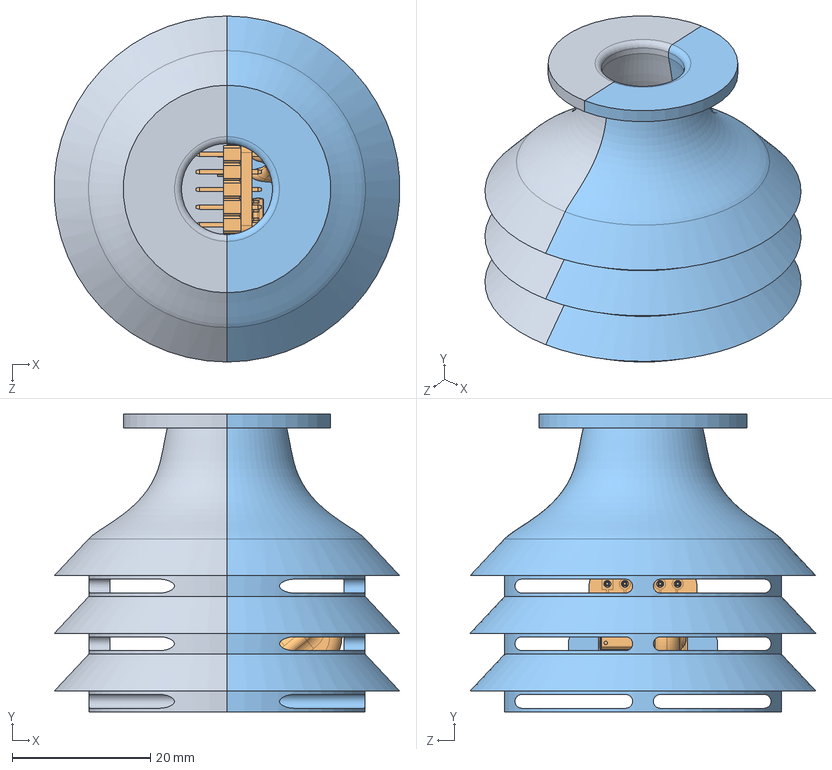
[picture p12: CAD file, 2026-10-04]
hardware/mechanical/model/assembly/sensor assembly.SLDASM
49.9 x 43.0 x 50.0 mm
sensor holder 2
RH,Tem sensor
sensor holder

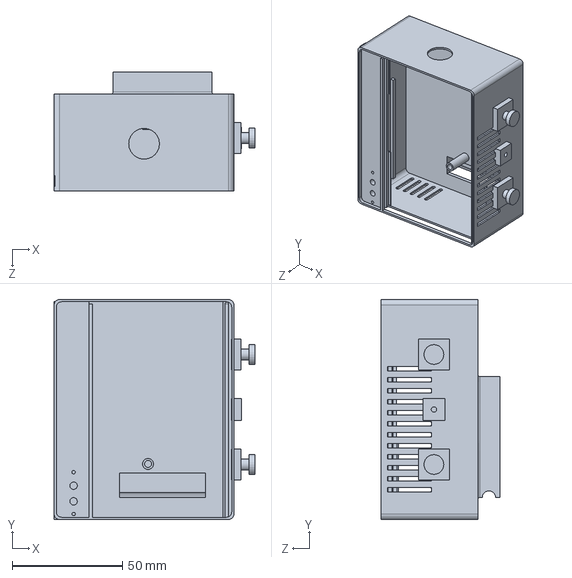
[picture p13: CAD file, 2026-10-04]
hardware/mechanical/model/parts/Main body.SLDPRT
91.3 x 100.0 x 54.0 mm

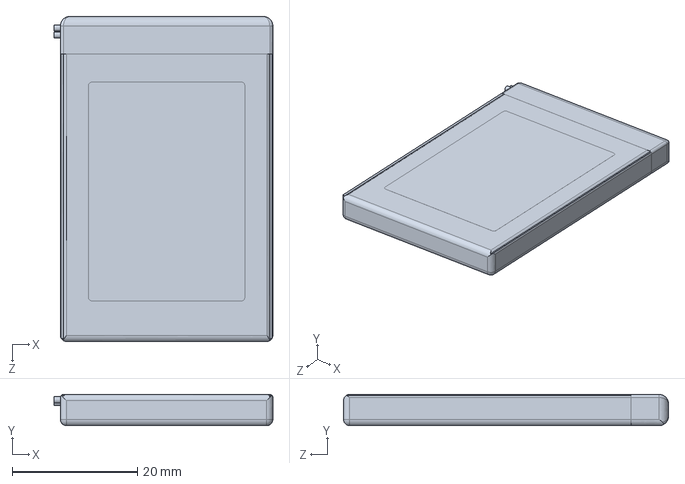
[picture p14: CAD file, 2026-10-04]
hardware/mechanical/model/parts/Li-iron Battery 1000mAh.SLDPRT
35.0 x 5.01 x 52.0 mm

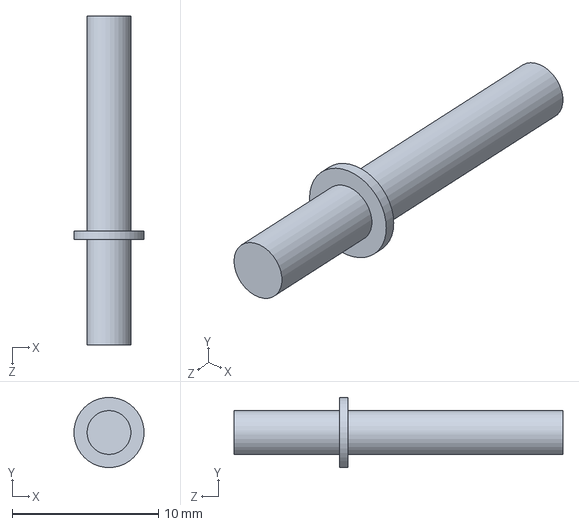
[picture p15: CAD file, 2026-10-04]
hardware/mechanical/model/parts/Button plunger 2.SLDPRT
4.80 x 4.80 x 22.5 mm

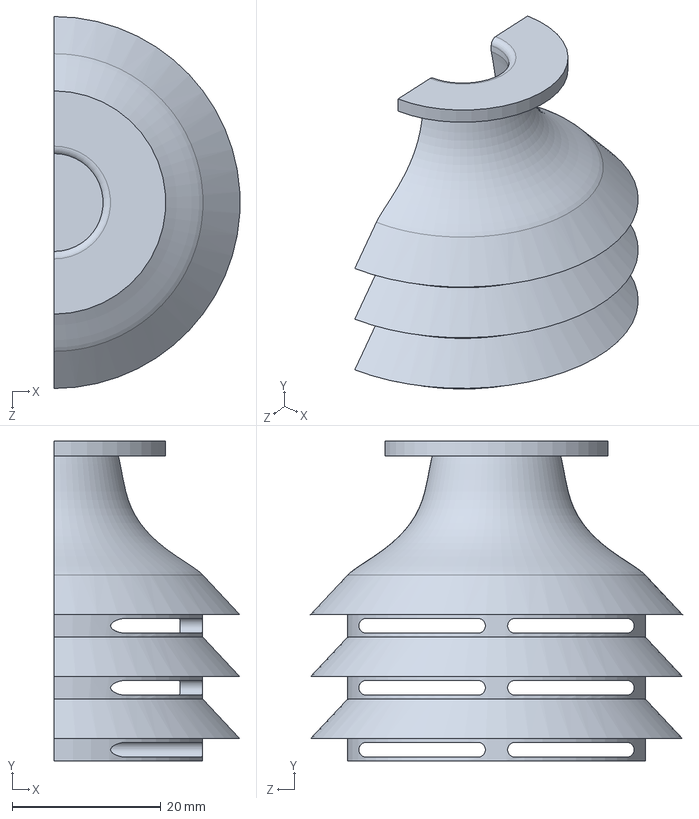
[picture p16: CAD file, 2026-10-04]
hardware/mechanical/model/parts/sensor holder.SLDPRT
25.0 x 43.0 x 50.0 mm

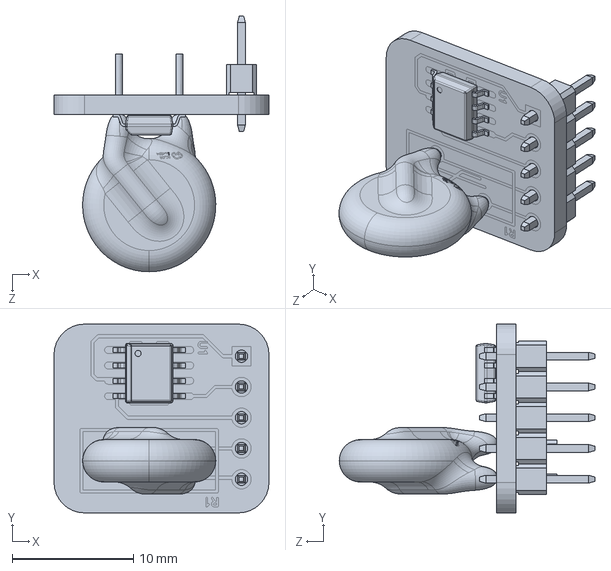
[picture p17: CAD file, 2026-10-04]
hardware/mechanical/model/parts/RH,Tem sensor.SLDPRT
17.8 x 15.6 x 21.1 mm

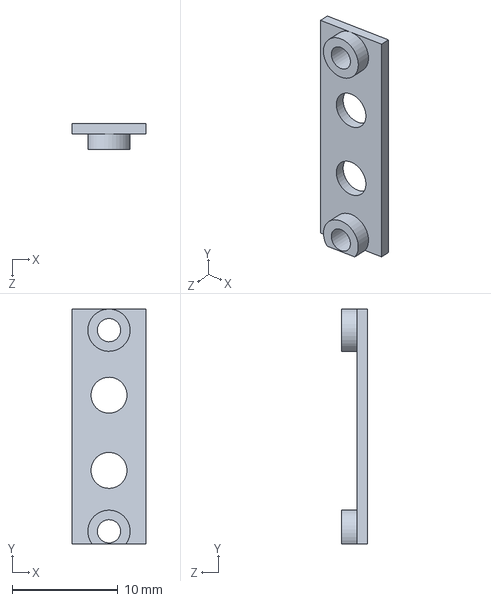
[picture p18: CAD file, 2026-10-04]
hardware/mechanical/model/parts/Button_retainer.SLDPRT
7.00 x 22.2 x 2.50 mm

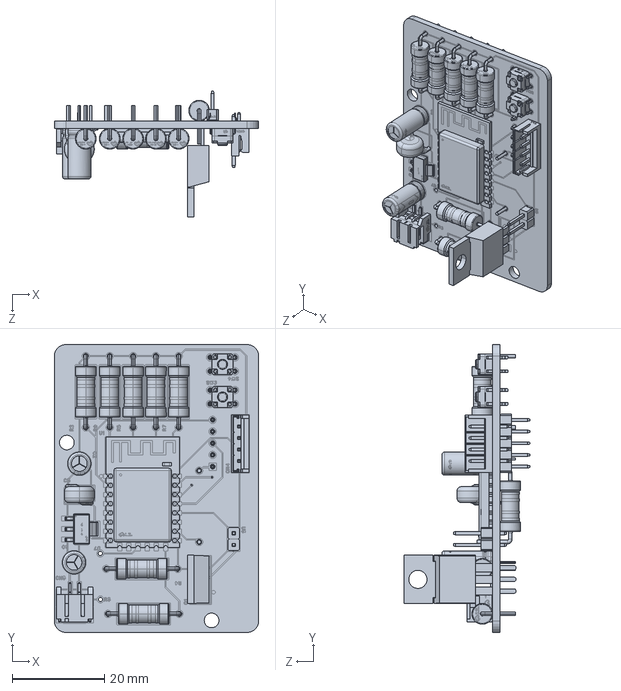
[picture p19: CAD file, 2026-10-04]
hardware/mechanical/model/parts/pcb.SLDPRT
44.4 x 62.6 x 27.3 mm

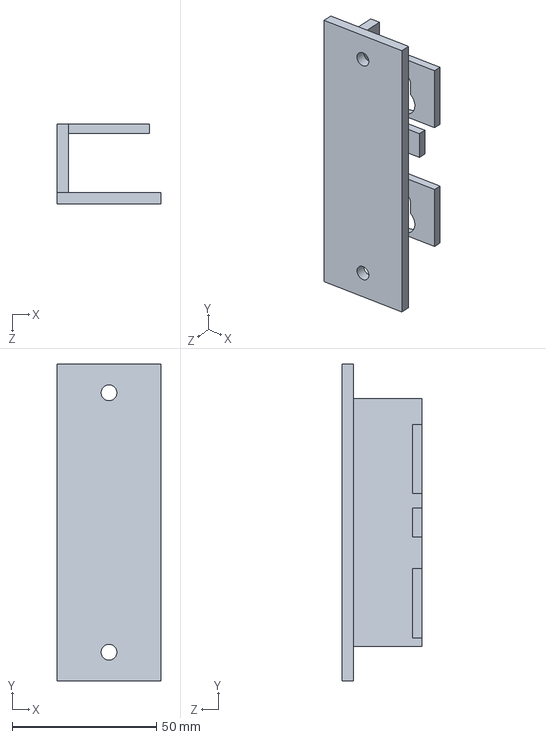
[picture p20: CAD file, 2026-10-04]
hardware/mechanical/model/parts/Side wall hanger.SLDPRT
36.0 x 110.0 x 27.7 mm

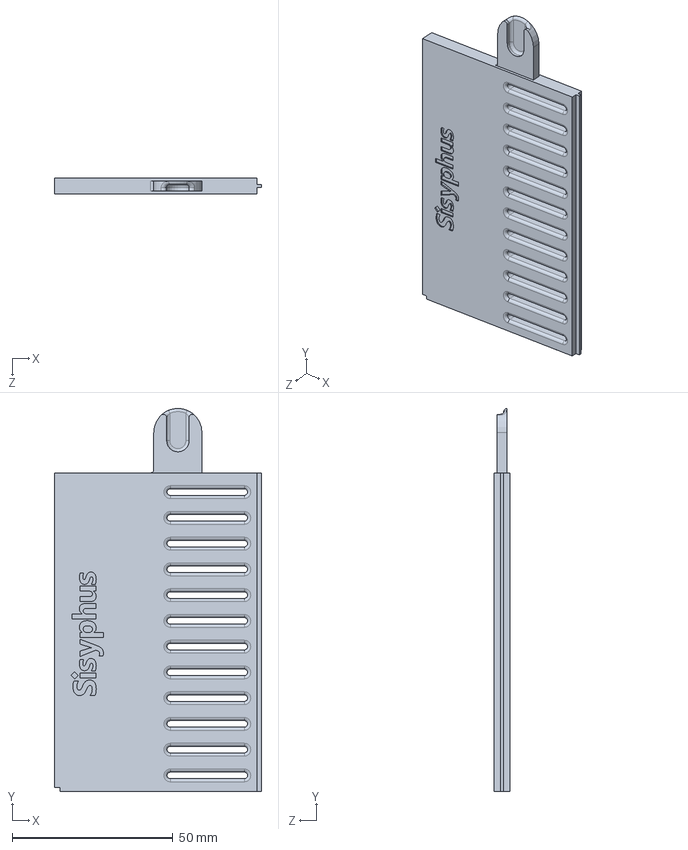
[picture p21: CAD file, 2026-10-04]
hardware/mechanical/model/parts/Buttons_closer.SLDPRT
64.3 x 119.0 x 5.00 mm

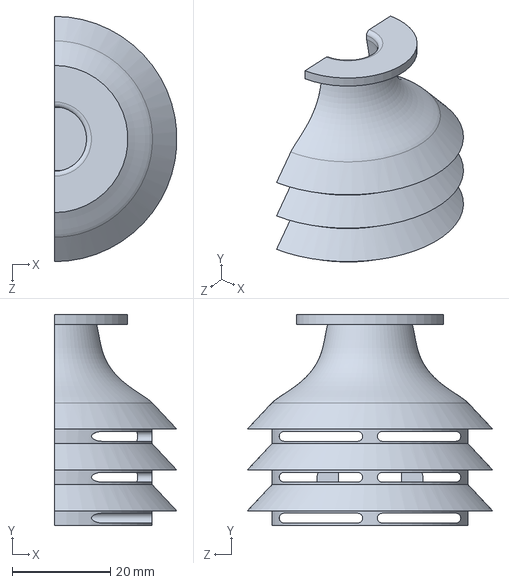
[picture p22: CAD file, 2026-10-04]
hardware/mechanical/model/parts/sensor holder 2.SLDPRT
25.0 x 43.0 x 50.0 mm

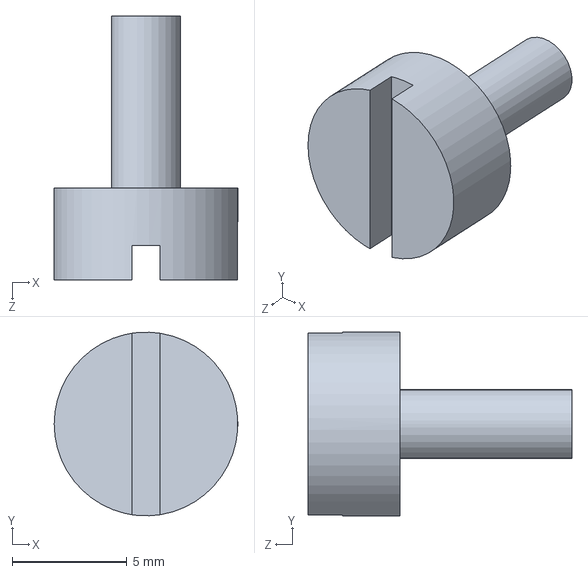
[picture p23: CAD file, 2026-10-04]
hardware/mechanical/model/parts/Hanger lock screw envelope.SLDPRT
8.00 x 8.00 x 11.5 mm

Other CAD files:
hardware/mechanical/model/assembly/Cable_7-Buttons_Assem14-001.SLDASM
hardware/mechanical/model/assembly/Cable_8-Buttons_Assem14.SLDASM
hardware/mechanical/model/assembly/Cable_7-Buttons_Assem14.SLDASM
hardware/mechanical/model/parts/Button plunger 1.SLDPRT
hardware/mechanical/2D Drawings/Node enclosure.SLDDRW

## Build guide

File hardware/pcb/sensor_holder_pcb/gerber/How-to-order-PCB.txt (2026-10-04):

How to Order PCB

Please refer to:
https://prodocs.easyeda.com/en/pcb/order-order-pcb/index.html

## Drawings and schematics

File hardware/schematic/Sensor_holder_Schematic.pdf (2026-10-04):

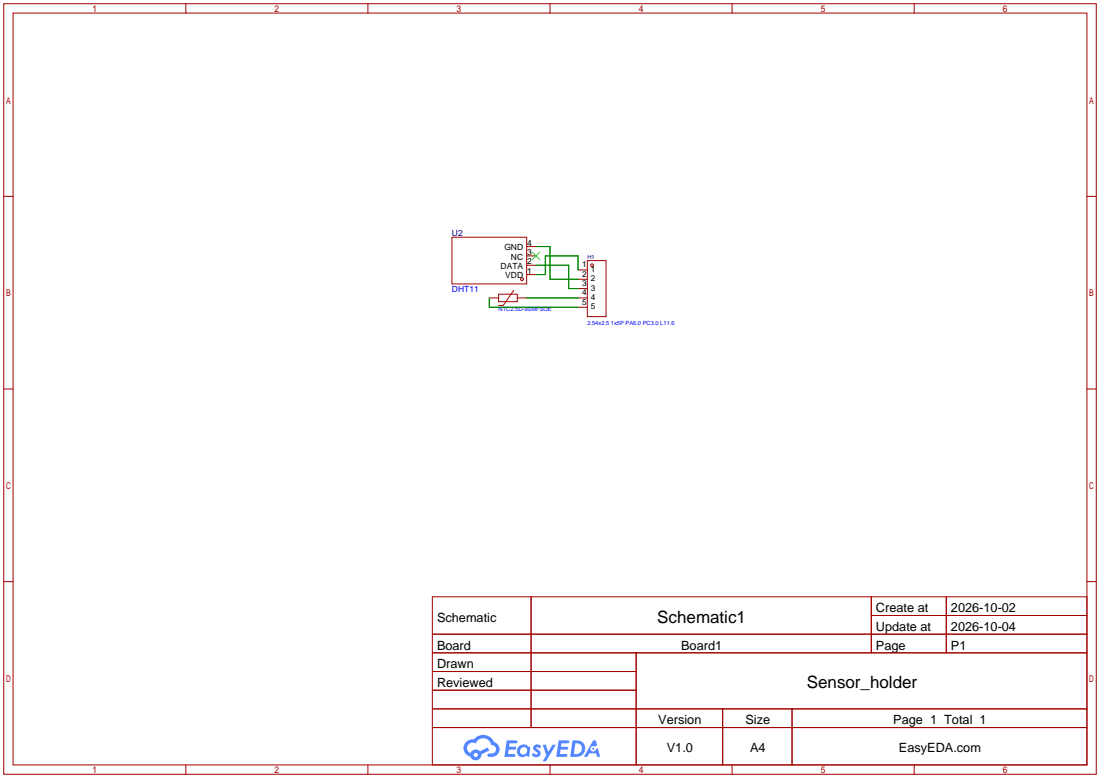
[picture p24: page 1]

Schematic | Schematic1 | Create at | 2026-10-02

Update at | 2026-10-04

Board | Board1 | Page | P1
Drawn | | Sensor_holder
Reviewed

Version | Size | Page 1 Total 1
V1.0 | A4 | EasyEDA.com

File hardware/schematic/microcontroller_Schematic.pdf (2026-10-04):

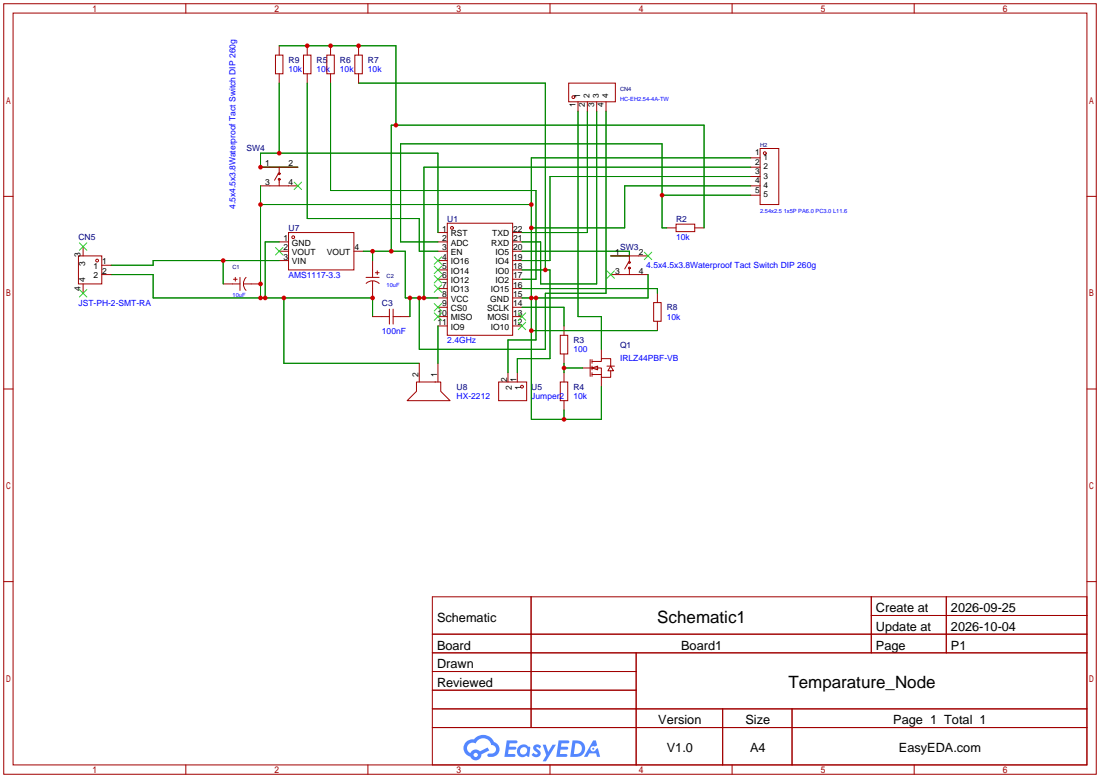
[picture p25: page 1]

JST-PH-2-SMT-RA

Schematic | Schematic1 | Create at | 2026-09-25

Update at | 2026-10-04

Board | Board1 | Page | P1
Drawn | | Temparature_Node
Reviewed

Version | Size | Page 1 Total 1
V1.0 | A4 | EasyEDA.com

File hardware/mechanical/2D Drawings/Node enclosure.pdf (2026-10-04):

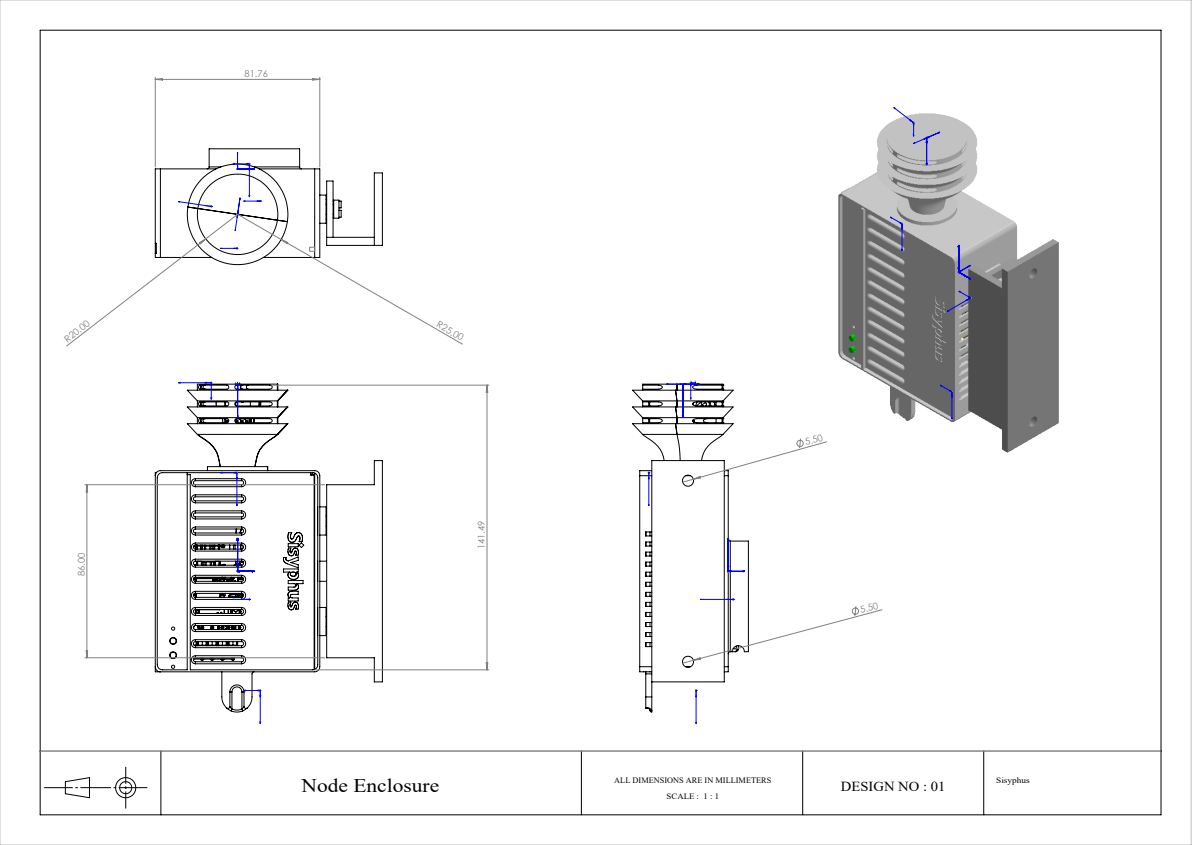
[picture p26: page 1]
Node Enclosure; ALL DIMENSIONS ARE IN MILLIMETERS; SCALE : 1 : 1; DESIGN NO : 01; Sisyphus

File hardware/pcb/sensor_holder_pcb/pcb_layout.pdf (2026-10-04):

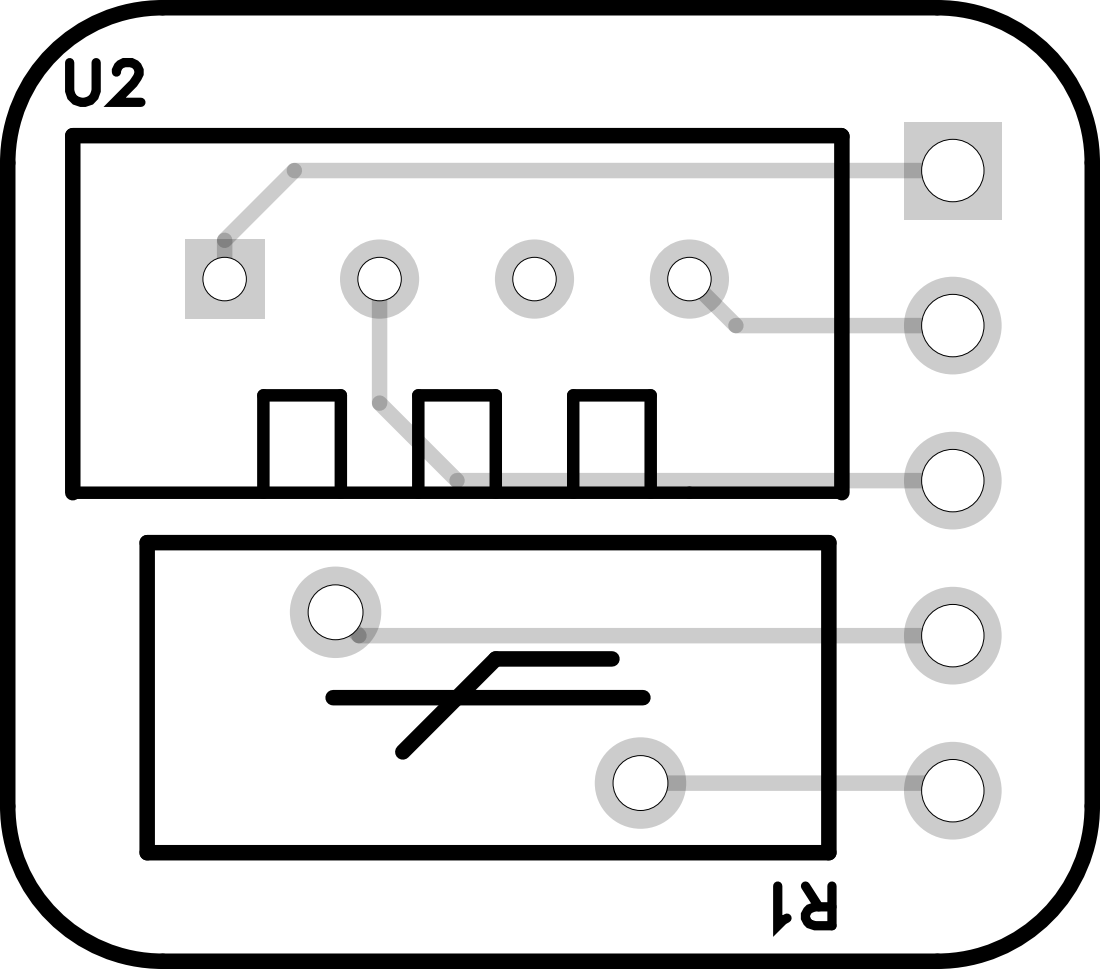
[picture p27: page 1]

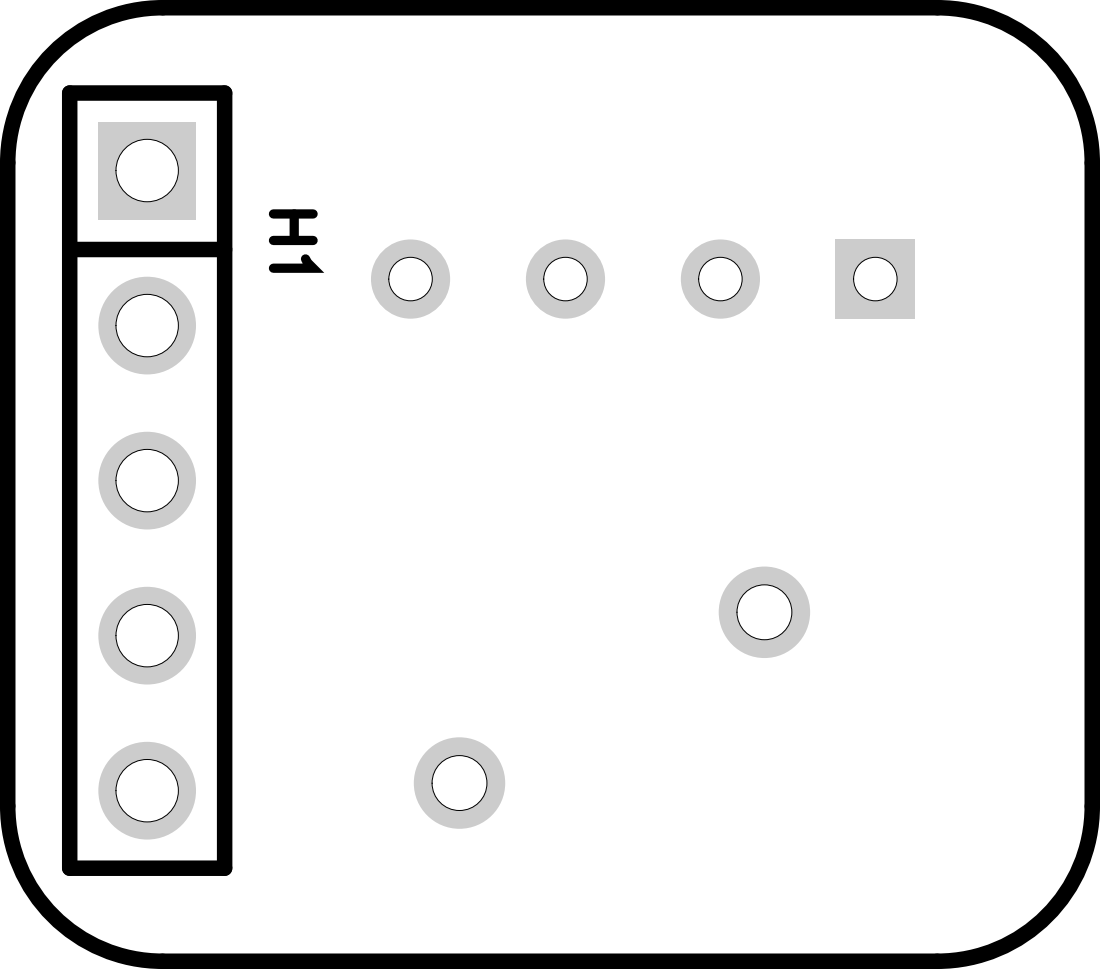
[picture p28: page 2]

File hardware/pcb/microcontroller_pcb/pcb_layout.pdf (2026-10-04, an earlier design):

SW3

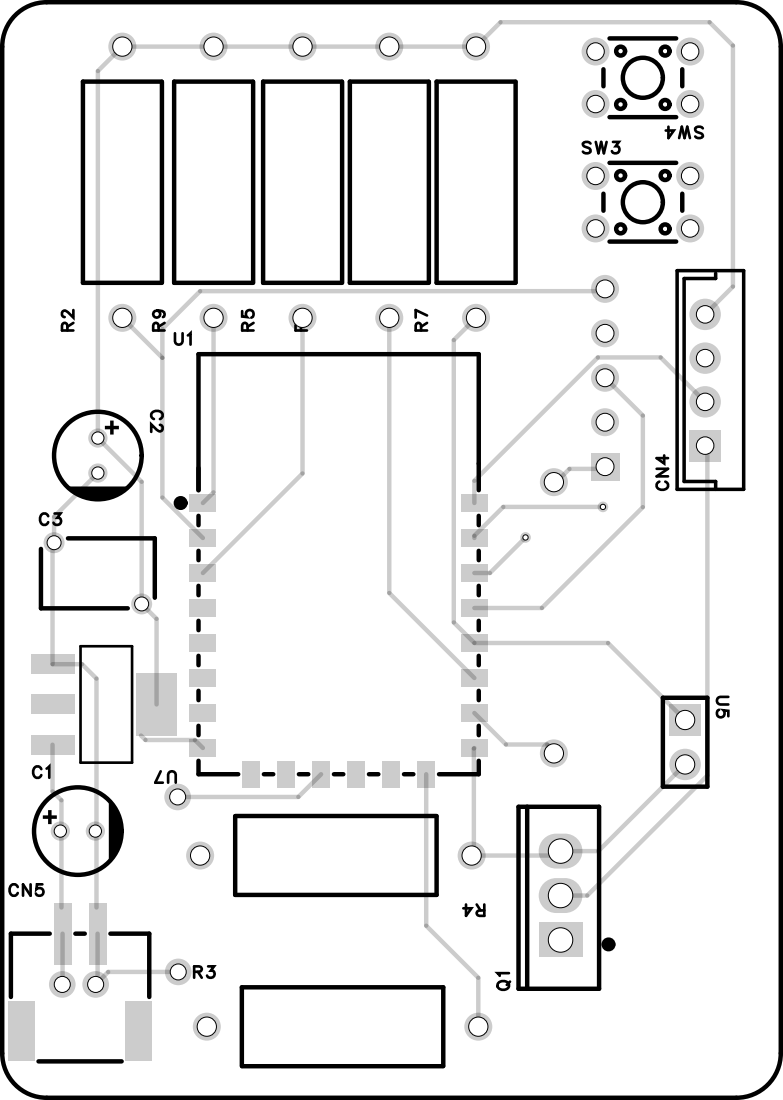
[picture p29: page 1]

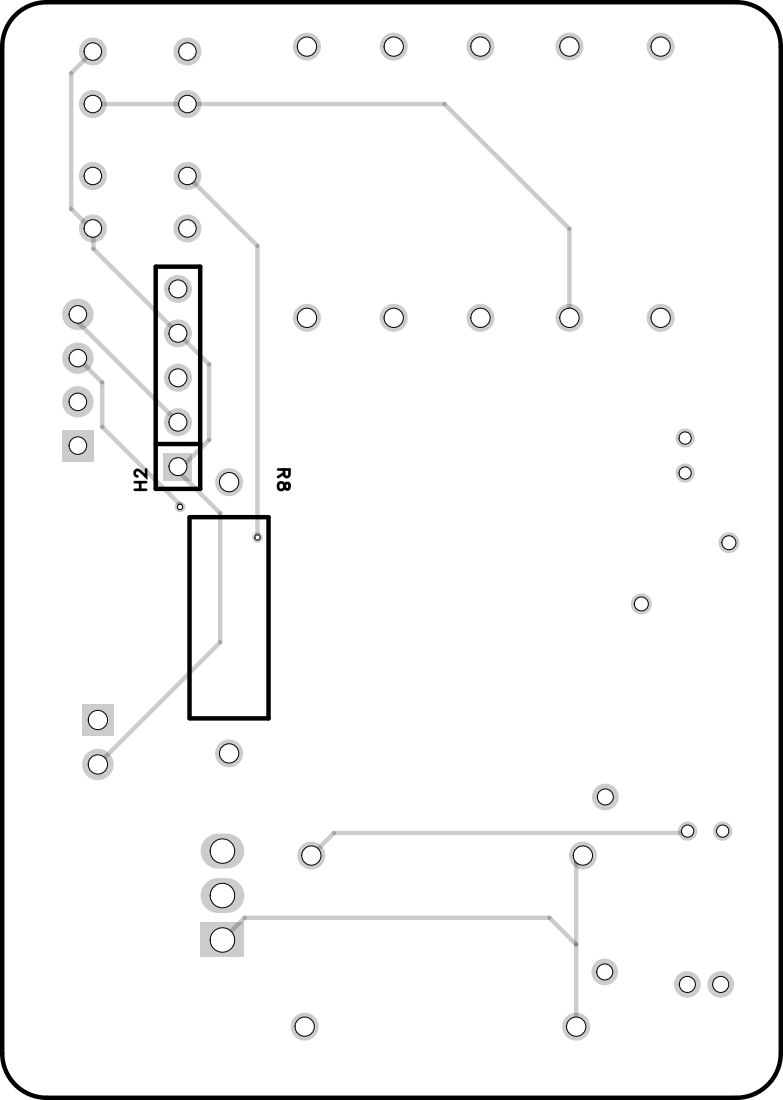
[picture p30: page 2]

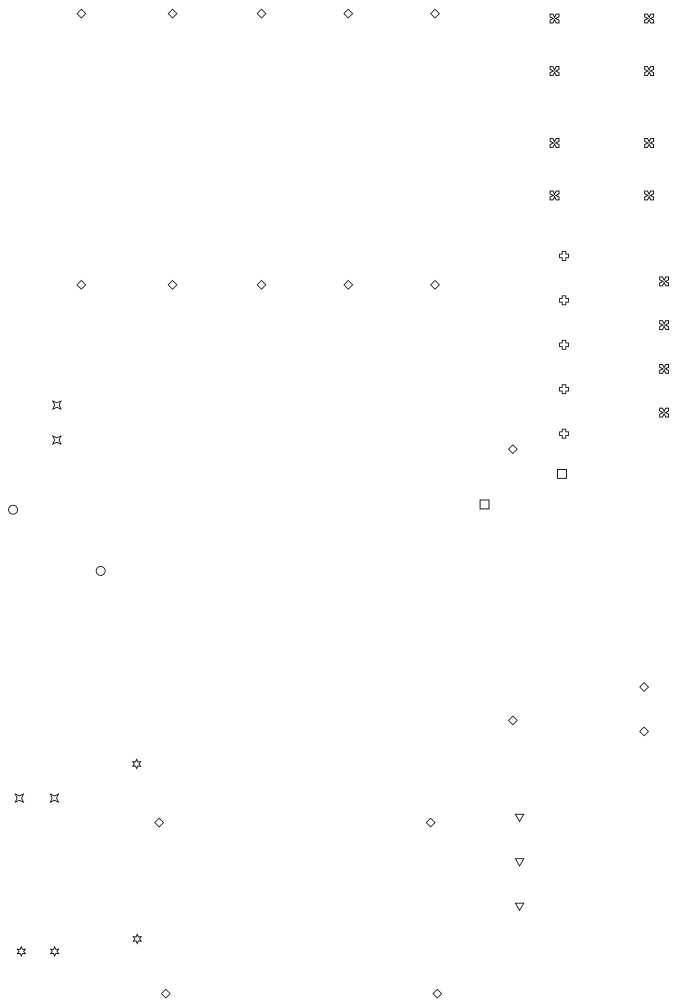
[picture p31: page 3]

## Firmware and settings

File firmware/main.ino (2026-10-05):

#include <OneWire.h>
#include <DallasTemperature.h>
#include <TinyGPSPlus.h>
#include <Wire.h>
#include <Adafruit_GFX.h>
#include <Adafruit_SSD1306.h>
#include <Preferences.h>
#include <WiFi.h>
#include <PubSubClient.h>
#include <math.h>


char NODE_ID[32] = "NODE02";

String deviceMAC;
String provisioningTopic;
bool nodeProvisioned = false;




const char* WIFI_SSID = "Juththis";
const char* WIFI_PASSWORD = "Sihthtuj";

const char* MQTT_SERVER = "10.22.97.69";
const uint16_t MQTT_PORT = 1883;

WiFiClient mqttWiFiClient;
PubSubClient mqttClient(mqttWiFiClient);

unsigned long lastMQTTReconnectAttempt = 0;
const unsigned long MQTT_RECONNECT_INTERVAL = 5000;

unsigned long lastWiFiReconnectAttempt = 0;
const unsigned long WIFI_RECONNECT_INTERVAL = 10000;

unsigned long lastMQTTPublish = 0;
const unsigned long MQTT_PUBLISH_INTERVAL = 1000;


// ============================================================
// PIN DEFINITIONS
// ============================================================

#define DS18B20_PIN 4
#define NTC_PIN     34

// GPS UART
#define GPS_RX_PIN  16     // ESP32 RX <- GPS TX
#define GPS_TX_PIN  17     // ESP32 TX -> GPS RX

// OLED I2C
#define OLED_SDA    21
#define OLED_SCL    22

// NEW POWER CONTROL
#define GPS_POWER_PIN   34
#define OLED_POWER_PIN  34
#define BUTTON_PIN      27


// ============================================================
// OLED
// ============================================================

#define SCREEN_WIDTH  128
#define SCREEN_HEIGHT 64
#define OLED_RESET    -1
#define OLED_ADDRESS  0x3C

Adafruit_SSD1306 display(
  SCREEN_WIDTH,
  SCREEN_HEIGHT,
  &Wire,
  OLED_RESET
);

bool oledPowered = false;
bool oledAvailable = false;


// ============================================================
// OLED DISPLAY STATES
// ============================================================

enum OLEDMode
{
  OLED_NORMAL,
  OLED_GPS_UPDATING,
  OLED_GPS_UPDATED,
  OLED_GPS_TIMEOUT
};

OLEDMode oledMode = OLED_NORMAL;


// ============================================================
// DS18B20
// ============================================================

OneWire oneWire(DS18B20_PIN);
DallasTemperature ds18b20(&oneWire);


// ============================================================
// GPS
// ============================================================

TinyGPSPlus gps;
HardwareSerial gpsSerial(2);

bool gpsPowered = false;
bool gpsUpdating = false;

unsigned long gpsUpdateStart = 0;
unsigned long gpsFixCountAtStart = 0;

const unsigned long GPS_TIMEOUT = 120000UL; // 2 minutes


// ============================================================
// GPS LOCATION
// Saved in ESP32 non-volatile memory
// ============================================================

Preferences preferences;

double latitude = 0.0;
double longitude = 0.0;

uint32_t satellites = 0;

bool gpsLocationValid = false;


// ============================================================
// NTC PARAMETERS
// ============================================================

const float R_FIXED = 10000.0;
const float R_REF = 10000.0;
const float T_REF_K = 298.15;
const float BETA = 3950.0;

const int ADC_MAX = 4095;
const int ADC_SAMPLES = 20;


const float DS_CAL_A = 1.0000;
const float DS_CAL_B = 0.0000;


const float NTC_CAL_A = 1.008076;
const float NTC_CAL_B = -2.507173;


// SENSOR NOISE

const float DS_SIGMA = 0.0251;
const float NTC_SIGMA = 0.0540;

const float DS_VARIANCE =
  DS_SIGMA * DS_SIGMA;

const float NTC_VARIANCE =
  NTC_SIGMA * NTC_SIGMA;



const float MIN_VALID_TEMP = -20.0;
const float MAX_VALID_TEMP = 100.0;

const float MAX_STEP_CHANGE = 8.0;


// ============================================================
// PREVIOUS VALUES FOR OUTLIER DETECTION
// ============================================================

float previousDS = 0.0;
float previousNTC = 0.0;

bool previousDSAvailable = false;
bool previousNTCAvailable = false;


// ============================================================
// KALMAN FILTER
// ============================================================

float kalmanTemperature = 0.0;
float kalmanP = 1.0;

bool kalmanInitialized = false;

const float PROCESS_SIGMA = 0.10;

const float PROCESS_VARIANCE =
  PROCESS_SIGMA * PROCESS_SIGMA;


// ============================================================
// CURRENT VALUES
// Used by OLED
// ============================================================

float currentFinalTemperature = 0.0;

// Latest calibrated individual sensor values for MQTT/dashboard.
float currentDSTemperature = 0.0;
float currentNTCTemperature = 0.0;

bool currentFusionValid = false;
bool currentDSValid = false;
bool currentNTCValid = false;


// ============================================================
// MEASUREMENT TIMING
// ============================================================

unsigned long lastMeasurementTime = 0;

const unsigned long MEASUREMENT_INTERVAL = 1000;


// ============================================================
// BUTTON
// ============================================================

const unsigned long BUTTON_DEBOUNCE = 40;
const unsigned long LONG_PRESS_TIME = 2000;

bool lastButtonReading = HIGH;
bool stableButtonState = HIGH;

unsigned long lastButtonChange = 0;
unsigned long buttonPressStart = 0;

bool buttonPressActive = false;
bool longPressTriggered = false;


// ============================================================
// OLED TIMING
// ============================================================

const unsigned long OLED_SHORT_TIME = 10000;
const unsigned long OLED_AFTER_GPS_TIME = 5000;

unsigned long oledOffTime = 0;
unsigned long lastOLEDRefresh = 0;

const unsigned long OLED_REFRESH_INTERVAL = 250;


// ============================================================
// FUNCTION PROTOTYPES
// ============================================================

void refreshOLED();
void serviceButton();
void serviceGPS();
void serviceOLED();
void serviceBackground();

// MQTT / Wi-Fi
void setupWiFi();
void setupMQTT();
void serviceMQTT();
bool reconnectMQTT();
void publishNodeDiscovery();
void publishMQTTTelemetry();
void mqttCallback(char* topic, byte* payload, unsigned int length);
void loadNodeID();
void saveNodeID(const char* newID);
String getMACCompact();


// ============================================================
// NODE ID / PROVISIONING
// ============================================================

String getMACCompact()
{
  String mac = WiFi.macAddress();

  mac.replace(":", "");

  mac.toUpperCase();

  return mac;
}


void loadNodeID()
{
  deviceMAC = getMACCompact();

  preferences.begin("nodecfg", true);

  String savedID =
    preferences.getString("node_id", "");

  preferences.end();

  if (savedID.length() > 0)
  {
    savedID.toCharArray(
      NODE_ID,
      sizeof(NODE_ID)
    );

    nodeProvisioned = true;
  }
  else
  {
    // Unique temporary ID.
    String temporaryID =
      "ESP32_" +
      deviceMAC.substring(6);

    temporaryID.toCharArray(
      NODE_ID,
      sizeof(NODE_ID)
    );

    nodeProvisioned = false;
  }

  provisioningTopic =
    "nodes/provision/" +
    deviceMAC;
}


void saveNodeID(const char* newID)
{
  if (newID == nullptr)
    return;

  String cleanID =
    String(newID);

  cleanID.trim();

  if (
    cleanID.length() == 0 ||
    cleanID.length() >= sizeof(NODE_ID)
  )
  {
    return;
  }

  cleanID.toCharArray(
    NODE_ID,
    sizeof(NODE_ID)
  );

  preferences.begin("nodecfg", false);

  preferences.putString(
    "node_id",
    cleanID
  );

  preferences.end();

  nodeProvisioned = true;

  Serial.print("Node ID assigned by dashboard: ");
  Serial.println(NODE_ID);

  delay(300);

  ESP.restart();
}


// ============================================================
// WI-FI
// ============================================================

void setupWiFi()
{
  Serial.println();
  Serial.print("Connecting to Wi-Fi: ");
  Serial.println(WIFI_SSID);

  WiFi.mode(WIFI_STA);

  WiFi.begin(
    WIFI_SSID,
    WIFI_PASSWORD
  );

  unsigned long start =
    millis();

  while (
    WiFi.status() != WL_CONNECTED
    &&
    millis() - start < 20000
  )
  {
    delay(250);
    Serial.print(".");
  }

  Serial.println();

  if (WiFi.status() == WL_CONNECTED)
  {
    Serial.print("Wi-Fi connected. IP: ");
    Serial.println(WiFi.localIP());

    Serial.print("MAC: ");
    Serial.println(WiFi.macAddress());
  }
  else
  {
    Serial.println(
      "Wi-Fi connection failed. "
      "Node will continue local operation."
    );
  }
}


// ============================================================
// MQTT TOPIC HELPERS
// ============================================================

String mqttDataTopic()
{
  return
    String("nodes/") +
    NODE_ID +
    "/data";
}


String mqttStatusTopic()
{
  return
    String("nodes/") +
    NODE_ID +
    "/status";
}


String mqttInfoTopic()
{
  return
    String("nodes/") +
    NODE_ID +
    "/info";
}


// ============================================================
// MQTT SETUP
// ============================================================

void setupMQTT()
{
  mqttClient.setServer(
    MQTT_SERVER,
    MQTT_PORT
  );

  mqttClient.setCallback(
    mqttCallback
  );

  mqttClient.setBufferSize(512);
}



void mqttCallback(
  char* topic,
  byte* payload,
  unsigned int length
)
{
  String message;

  for (
    unsigned int i = 0;
    i < length;
    i++
  )
  {
    message +=
      (char)payload[i];
  }

  message.trim();

  if (
    String(topic) ==
    provisioningTopic
  )
  {
    Serial.print(
      "Provisioning command received: "
    );

    Serial.println(message);

    saveNodeID(
      message.c_str()
    );
  }
}




void publishNodeDiscovery()
{
  if (!mqttClient.connected())
    return;

  String topic =
    "nodes/" +
    String(NODE_ID) +
    "/discovery";

  String payload =
    "{"
    "\"node\":\"" + String(NODE_ID) + "\","
    "\"mac\":\"" + WiFi.macAddress() + "\","
    "\"ip\":\"" + WiFi.localIP().toString() + "\","
    "\"provisioned\":" +
    String(nodeProvisioned ? "true" : "false") +
    ","
    "\"gps\":true,"
    "\"temperatureSensors\":2,"
    "\"fusedTemperature\":true"
    "}";

  mqttClient.publish(
    topic.c_str(),
    payload.c_str(),
    true
  );
}


// ============================================================
// MQTT CONNECTION
// ============================================================

bool reconnectMQTT()
{
  if (
    WiFi.status() != WL_CONNECTED
  )
  {
    return false;
  }

  Serial.print(
    "Connecting to MQTT broker..."
  );

  String clientID =
    "ESP32_" +
    deviceMAC;

  String statusTopic =
    mqttStatusTopic();

  bool connected =
    mqttClient.connect(
      clientID.c_str(),
      nullptr,
      nullptr,
      statusTopic.c_str(),
      1,
      true,
      "offline"
    );

  if (!connected)
  {
    Serial.print(
      " failed, state="
    );

    Serial.println(
      mqttClient.state()
    );

    return false;
  }

  Serial.println(
    " connected."
  );

  // Online status is retained.
  mqttClient.publish(
    statusTopic.c_str(),
    "online",
    true
  );

  // Receive provisioning commands for this exact ESP32.
  mqttClient.subscribe(
    provisioningTopic.c_str(),
    1
  );

  publishNodeDiscovery();

  return true;
}


// ============================================================
// MQTT SERVICE
//
// This is intentionally non-blocking.
// Existing temperature/GPS/button logic continues to run.
// ============================================================

void serviceMQTT()
{
  // Recover Wi-Fi without blocking the sensor logic.
  if (
    WiFi.status() != WL_CONNECTED
  )
  {
    if (
      millis() -
      lastWiFiReconnectAttempt
      >=
      WIFI_RECONNECT_INTERVAL
    )
    {
      lastWiFiReconnectAttempt =
        millis();

      WiFi.reconnect();
    }

    return;
  }

  if (!mqttClient.connected())
  {
    if (
      millis() -
      lastMQTTReconnectAttempt
      >=
      MQTT_RECONNECT_INTERVAL
    )
    {
      lastMQTTReconnectAttempt =
        millis();

      reconnectMQTT();
    }

    return;
  }

  mqttClient.loop();
}


// ============================================================
// MQTT TELEMETRY
//
// One JSON packet contains the complete node state.
//
// t1     = calibrated DS18B20
// t2     = calibrated NTC
// fused  = WLS + Kalman temperature
// lat/lon = saved GPS location
// ============================================================

void publishMQTTTelemetry()
{
  if (!mqttClient.connected())
    return;

  if (
    millis() -
    lastMQTTPublish
    <
    MQTT_PUBLISH_INTERVAL
  )
  {
    return;
  }

  lastMQTTPublish =
    millis();

  String topic =
    mqttDataTopic();

  String payload =
    "{";

  payload +=
    "\"node\":\"" +
    String(NODE_ID) +
    "\",";

  payload +=
    "\"mac\":\"" +
    WiFi.macAddress() +
    "\",";

  payload +=
    "\"lat\":" +
    String(
      gpsLocationValid ?
      latitude :
      0.0,
      6
    ) +
    ",";

  payload +=
    "\"lon\":" +
    String(
      gpsLocationValid ?
      longitude :
      0.0,
      6
    ) +
    ",";

  payload +=
    "\"gpsValid\":" +
    String(
      gpsLocationValid ?
      "true" :
      "false"
    ) +
    ",";

  payload +=
    "\"satellites\":" +
    String(satellites) +
    ",";

  payload +=
    "\"t1\":" +
    String(
      currentDSValid ?
      currentDSTemperature :
      0.0,
      3
    ) +
    ",";

  payload +=
    "\"t2\":" +
    String(
      currentNTCValid ?
      currentNTCTemperature :
      0.0,
      3
    ) +
    ",";

  payload +=
    "\"fused\":" +
    String(
      currentFusionValid ?
      currentFinalTemperature :
      0.0,
      3
    ) +
    ",";

  payload +=
    "\"dsValid\":" +
    String(
      currentDSValid ?
      "true" :
      "false"
    ) +
    ",";

  payload +=
    "\"ntcValid\":" +
    String(
      currentNTCValid ?
      "true" :
      "false"
    );

  payload +=
    "}";

  mqttClient.publish(
    topic.c_str(),
    payload.c_str(),
    false
  );
}


// ============================================================
// CALIBRATION
// ============================================================

float calibrateDS18B20(float rawTemperature)
{
  return
    DS_CAL_A * rawTemperature
    +
    DS_CAL_B;
}


float calibrateNTC(float rawTemperature)
{
  return
    NTC_CAL_A * rawTemperature
    +
    NTC_CAL_B;
}


// ============================================================
// LOAD SAVED GPS LOCATION
// ============================================================

void loadSavedGPS()
{
  preferences.begin("gpsloc", true);

  gpsLocationValid =
    preferences.getBool(
      "valid",
      false
    );

  if (gpsLocationValid)
  {
    latitude =
      preferences.getDouble(
        "lat",
        0.0
      );

    longitude =
      preferences.getDouble(
        "lon",
        0.0
      );
  }

  preferences.end();
}


// ============================================================
// SAVE GPS LOCATION
// ============================================================

void saveGPS()
{
  preferences.begin("gpsloc", false);

  preferences.putDouble(
    "lat",
    latitude
  );

  preferences.putDouble(
    "lon",
    longitude
  );

  preferences.putBool(
    "valid",
    true
  );

  preferences.end();

  Serial.println(
    "GPS location saved to ESP32 memory."
  );
}


// ============================================================
// GPS POWER ON
// ============================================================

void gpsPowerOn()
{
  if (gpsPowered)
    return;

  Serial.println("GPS POWER ON");

  // MOSFET ON
  digitalWrite(
    GPS_POWER_PIN,
    HIGH
  );

  delay(200);

  // Restart UART
  gpsSerial.begin(
    9600,
    SERIAL_8N1,
    GPS_RX_PIN,
    GPS_TX_PIN
  );

  // Remove anything currently in UART buffer
  while (gpsSerial.available())
  {
    gpsSerial.read();
  }

  gpsPowered = true;
}


// ============================================================
// GPS POWER OFF
// ============================================================

void gpsPowerOff()
{
  if (!gpsPowered)
    return;

  Serial.println("GPS POWER OFF");

  // Stop UART first
  gpsSerial.end();

  // Do not drive the GPS signal pins while GPS is OFF
  pinMode(
    GPS_RX_PIN,
    INPUT
  );

  pinMode(
    GPS_TX_PIN,
    INPUT
  );

  // MOSFET OFF
  digitalWrite(
    GPS_POWER_PIN,
    LOW
  );

  gpsPowered = false;
}


// ============================================================
// OLED POWER ON
// ============================================================

void oledPowerOn()
{
  if (oledPowered)
    return;

  Serial.println("OLED POWER ON");

  // MOSFET ON
  digitalWrite(
    OLED_POWER_PIN,
    HIGH
  );

  oledPowered = true;

  delay(50);

  Wire.begin(
    OLED_SDA,
    OLED_SCL
  );

  oledAvailable =
    display.begin(
      SSD1306_SWITCHCAPVCC,
      OLED_ADDRESS
    );

  if (!oledAvailable)
  {
    Serial.println(
      "WARNING: OLED not detected."
    );

    return;
  }

  display.clearDisplay();

  refreshOLED();
}


// ============================================================
// OLED POWER OFF
// ============================================================

void oledPowerOff()
{
  if (!oledPowered)
    return;

  Serial.println("OLED POWER OFF");

  if (oledAvailable)
  {
    display.clearDisplay();
    display.display();
  }

  // Stop I2C first
  Wire.end();

  // Prevent back-power through SDA/SCL
  pinMode(
    OLED_SDA,
    INPUT
  );

  pinMode(
    OLED_SCL,
    INPUT
  );

  // MOSFET OFF
  digitalWrite(
    OLED_POWER_PIN,
    LOW
  );

  oledPowered = false;
  oledAvailable = false;
}


// ============================================================
// UPDATE OLED
// ============================================================

void refreshOLED()
{
  if (!oledPowered ||
      !oledAvailable)
  {
    return;
  }

  lastOLEDRefresh = millis();

  display.clearDisplay();

  display.setTextColor(
    SSD1306_WHITE
  );

  // ----------------------------------------------------------
  // NODE
  // ----------------------------------------------------------

  display.setTextSize(1);

  display.setCursor(
    0,
    0
  );

  display.print("NODE: ");
  display.println(NODE_ID);


  // ----------------------------------------------------------
  // TEMPERATURE
  // ----------------------------------------------------------

  display.setCursor(
    0,
    14
  );

  display.println(
    "FUSED TEMPERATURE"
  );

  display.setTextSize(2);

  display.setCursor(
    0,
    25
  );

  if (currentFusionValid)
  {
    display.print(
      currentFinalTemperature,
      1
    );

    display.print(" C");
  }
  else
  {
    display.print("--.- C");
  }


  // ----------------------------------------------------------
  // GPS STATUS
  // ----------------------------------------------------------

  display.setTextSize(1);

  display.setCursor(
    0,
    48
  );

  if (oledMode == OLED_GPS_UPDATING)
  {
    display.print("GPS: UPDATING");
  }

  else if (oledMode == OLED_GPS_UPDATED)
  {
    display.print("GPS: UPDATED");
  }

  else if (oledMode == OLED_GPS_TIMEOUT)
  {
    display.print("GPS: TIMEOUT");
  }

  else
  {
    if (gpsLocationValid)
    {
      display.print("GPS: SAVED");
    }
    else
    {
      display.print("GPS: NONE");
    }
  }



  // SENSOR STATUS

  display.setCursor(
    0,
    57
  );

  display.print("DS:");

  if (currentDSValid)
    display.print("OK");
  else
    display.print("ERR");


  display.print(" NTC:");

  if (currentNTCValid)
    display.print("OK");
  else
    display.print("ERR");


  display.display();
}


// ============================================================
// START GPS LOCATION UPDATE
// ============================================================

void startGPSUpdate()
{
  if (gpsUpdating)
    return;

  Serial.println();
  Serial.println(
    "LONG PRESS -> GPS UPDATE STARTED"
  );

  oledPowerOn();

  oledMode =
    OLED_GPS_UPDATING;

  refreshOLED();

  gpsPowerOn();

  gpsUpdating = true;

  gpsUpdateStart =
    millis();

  // Used so an OLD GPS fix is not accepted
  gpsFixCountAtStart =
    gps.sentencesWithFix();
}




void serviceGPS()
{
  if (!gpsPowered)
    return;

  while (gpsSerial.available() > 0)
  {
    gps.encode(
      gpsSerial.read()
    );
  }


  if (gps.satellites.isValid())
  {
    satellites =
      gps.satellites.value();
  }


  if (!gpsUpdating)
    return;




  if (
    gps.sentencesWithFix()
      >
    gpsFixCountAtStart
    &&
    gps.location.isValid()
  )
  {
    latitude =
      gps.location.lat();

    longitude =
      gps.location.lng();

    gpsLocationValid = true;


    Serial.println();

    Serial.println(
      "NEW GPS FIX RECEIVED"
    );

    Serial.print(
      "Latitude : "
    );

    Serial.println(
      latitude,
      6
    );

    Serial.print(
      "Longitude: "
    );

    Serial.println(
      longitude,
      6
    );


    // Save location
    saveGPS();


    gpsUpdating = false;

    // GPS no longer required
    gpsPowerOff();


    oledMode =
      OLED_GPS_UPDATED;

    oledOffTime =
      millis()
      +
      OLED_AFTER_GPS_TIME;

    refreshOLED();

    return;
  }


 
  // GPS TIMEOUT
  

  if (
    millis() -
    gpsUpdateStart
    >=
    GPS_TIMEOUT
  )
  {
    Serial.println(
      "GPS UPDATE TIMEOUT"
    );

    gpsUpdating = false;

    gpsPowerOff();

    oledMode =
      OLED_GPS_TIMEOUT;

    oledOffTime =
      millis()
      +
      OLED_AFTER_GPS_TIME;

    refreshOLED();
  }
}


// BUTTON SERVICE
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
void loop()
{
  // Button / OLED / GPS always serviced
  serviceBackground();


  // Temperature measurement
  if (
    millis() -
    lastMeasurementTime
    >=
    MEASUREMENT_INTERVAL
  )
  {
    lastMeasurementTime =
      millis();

    processTemperature();
  }
}

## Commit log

2026-10-04 update PCB files
2026-10-04 update gerber files
    [Drill_PTH_Through.DRL, Drill_PTH_Through_Via.DRL, Gerber_BoardOutlineLayer.GKO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]
2026-10-04 update PCB layouts
2026-10-04 update microcontroller PCB schematics
2026-10-04 Add files via upload
    update sensor holder schematic
2026-10-04 Update BOM
    [BOM_Board1_PCB.xlsx]
2026-10-04 Sensor Fusion
2026-10-05 Revise README for ESP-12F pinout and connections
    Updated the README to provide detailed pinout and connection information for the ESP-12F/ESP8266, including external connectors and components.
2026-10-05 Add initial README for Power Management
2026-10-05 update power analysis
2026-10-15 Create sisyphus-paddy-sensor-flow-sim
